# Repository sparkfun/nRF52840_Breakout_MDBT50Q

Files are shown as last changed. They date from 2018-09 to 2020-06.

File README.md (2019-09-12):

SparkFun Pro nRF52840 Mini - Bluetooth Development Board
========================================

SparkFun Pro nRF52840 Mini - Bluetooth Development Board

[*SparkFun Pro nRF52840 Mini - Bluetooth Development Board (DEV-15025)*](https://www.sparkfun.com/products/15025)

<Basic description of the part.>

Repository Contents
-------------------

* **/Documentation** - Data sheets, additional product information
* **/Firmware** -- nRF5 SDK and Arduino firmware components
  * **/Arduino** -- Board definitions and variants for installing in the [nRF52 Arduino Core](https://github.com/adafruit/Adafruit_nRF52_Arduino)
  * **/nRF5_SDK** -- Board definitions for use in the nRF5 SDK.
* **/Hardware** - Eagle design files (.brd, .sch)
* **/Production** - Production panel files (.brd)

Documentation
--------------
* **[Hookup Guide](https://learn.sparkfun.com/tutorials/sparkfun-pro-nrf52840-mini-hookup-guide)** - Basic hookup guide for the Pro nrf52840.

Product Versions
----------------
* [DEV-15025](https://www.sparkfun.com/products/15025)- The SparkFun Pro nRF52840 Mini is a breakout and development board for Nordic Semiconductor’s nRF52840 – a powerful combination of ARM Cortex-M4 CPU and 2.4 GHz Bluetooth radio. With the nRF52840 at the heart of your project, you’ll be presented with a seemingly endless list of project-possibilities.

License Information
-------------------

This product is _**open source**_! 

Please review the LICENSE.md file for license information.

If you have any questions or concerns on licensing, please visit the [SparkFun Forum](https://forum.sparkfun.com/index.php) and post a topic.

Distributed as-is; no warranty is given.

- Your friends at SparkFun.

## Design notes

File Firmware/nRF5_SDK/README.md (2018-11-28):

SparkFun nRF52840 Board Defs for the nRF5 SDK
=============================================

This directory includes any additional board definitions or examples for using the SparkFun nRF52840 boards with Nordic's nRF5 SDK.

The file structure should match that of the SDK.

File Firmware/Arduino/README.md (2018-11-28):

SparkFun Board Variant Definitions for Adafruit nRF52 Arduino Core
==================================================================

### Installation Instructions

To add SparkFun nRF52840 board support to the nRF52 Arduino core, one file (boards.txt) needs to be modified, and one new folder (variants/sparkfun\_nrf52840\_mini) needs to be copied in.

First, navigate to your Adafruit nRF52 core installation. If you installed via the board manager it'll probably be in one of these folders:

* Windows: %LOCALAPPDATA%\Arduino15\packages\adafruit\hardware\nrf52\<version>
* OS X: ~/Library/Arduino15/packages/adafruit/hardware/nrf52/<version>
* Linux: ~/.arduino15/packages/adafruit/hardware/nrf52/<version>

If you installed the core manually into your Arduino sketchbook, it'll be in a "hardware/adafruit/nrf52" in there.

Then **open boards.txt**. Scroll to the bottom and **paste the contents of sparkfun\_boards.txt** into the bottom of that file.

Then copy the contents of the "variants" folder in this directory into the "variants" folder of the original directory. Nothing should be overwritten, but a new "sparkfun\_nrf52840\_mini" directory should be added in.

### Directory Contents

* sparkfun\_boards.txt -- Additional board definitions for SparkFun nRF52840 boards 
* variants/sparkfun\_nrf52840\_mini -- SparkFun Pro nRF52840 Mini board (pin, LED, serial port) definitions.

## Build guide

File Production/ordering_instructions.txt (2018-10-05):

panel size, 174x107mm
PCB thickness, 1.6mm
number of layers, 2
soldermask color, Red
silkscreen color, White
oz copper, 1oz
finish, HASL lead free
stencils, none
pcs per panel, 12

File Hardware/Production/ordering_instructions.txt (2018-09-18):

panel size, 120x107mm
PCB thickness, 1.6mm
number of layers, 2
soldermask color, Black
silkscreen color, White
oz copper, 1oz
finish, HASL lead free
stencils, top
pcs per panel, 8

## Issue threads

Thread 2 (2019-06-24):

Sparkfun Bootloader Firmware

jchidley, 2019-06-24:
I recently corrupted the bootloader on my nRF52840.  I have 2 problems:
1. I need extra hardware to program the bootloader (J-Link for EDU for example or Nordic Semiconductor’s Development Kit).
2. I need a copy of Sparkfun’s  - which is “heavily based on” Adafruit’s.

Where can I find Sparkfun’s version of the firmware?

brhoff720, 2019-07-01:
See [SparkFun Forums](https://forum.sparkfun.com/viewtopic.php?f=114&t=50217) for solution.

Closed 2019-07-01.

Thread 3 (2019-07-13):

Adafruit nRF52 v0.11.1

jakelstr, 2019-07-13:
There seems to be an issue with this when using v0.11.1 of the Adafruit library. On v0.11.1, compiling gives an error that "Serial was not declared in this scope". Reverting to v0.10.1 cleared this error.

masonevans, 2019-07-16:
I experienced the same issue with the same resolution

santaimpersonator, 2019-07-17:
Adafruit switched to using TinyUSB in the core. We made changes in the `variant.cpp` and `boards.txt` files to update the board definition to use TinyUSB.

Using the new files will allow you to compile without this error and to use the example in our hookup guide.

Closed 2019-07-17.

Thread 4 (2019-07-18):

Compile error - fatal error: usb.h: No such file or directory

masonevans, 2019-07-18:
After the latest update seems like there is still an issue in variant.cpp.   I updated to Adafruit nRF52 v0.11.1, updated my boards.txt from the latest version in this repo, and copied the sparkfun_nrf52840_mini directory into my variants folder.

I now get the following error when I try to compile anything with the SparkFun board selected.  The other boards that come with the Adafruit nRF52 board definitions in work fine.

```
/Users/user/Library/Arduino15/packages/adafruit/hardware/nrf52/0.11.1/variants/sparkfun_nrf52840_mini/variant.cpp:26:10: fatal error: usb.h: No such file or directory
 #include "usb.h"
          ^~~~~~~
compilation terminated.
exit status 1
Error compiling for board SparkFun Pro nRF52840 Mini.
```

Commenting out the include from variant.cpp seems to fix the issue.  I do notice that Adafruit removed that include from all their variants when they removed the usb_init() call.

What's odd is that this seemed to work yesterday when I switched to v0.11.1 but today I switched back to v0.10.1 for some testing and when I went back to v0.11.1 I hit this.  Possibly something was cached somewhere?

santaimpersonator, 2019-07-20:
I missed it in the changes I made... to update the board def. Fixed now

Closed 2019-07-20.

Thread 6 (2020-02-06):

SPI issue without V_BUS supplied

deldipso, 2020-02-06:
I notified, the SPI doesn't seems to work if the USB is not plugged (or more directly V_BUS not supplied, it works if V_BUS only is supplied).
So it is not working with a battery or an external power supply on VIN or VBAT if I make a simple project with just SPI.
By not working I means the CLK and MOSI does toggle anymore in that situation. Just the CSB but it is controlled as a simple digital output pin.
This is not an power supply issue. I even unplugged my SPI sensor, I see CLK and MOSI with USB but no anymore with external supply.

SPI CFG:
SPI.begin();
SPI.setClockDivider(SPI_CLOCK_DIV64);
SPI.setDataMode(SPI_MODE2);
SPI.setBitOrder(LSBFIRST);

For an unknow reason, once I started to used the analogWrite() function, the SPI starts to work in any case, which is the workaround I currently use. It seems there is like a GPIO pin initialization issue when V_BUS is not supplied and the SPI only is used without analogWrite()...

Antdigapony, 2021-06-03:
@deldipso I have checked this issue without the USB plugged in and I have found that the problem was with the GND pin. If there is only VIN connected to the 3V3 power supply - there is a problem, that you have mentioned. But if you connect the GND pin from the power supply too - all is OK(by the way it's a correct way of powering).

Maybe, in your case there is something else or whatever, but in my case SPI worked correctly without USB plugged in.

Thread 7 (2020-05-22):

Serial1 Definition Missing

Phando, 2020-05-22:
Hello,
I am just getting started with the nrf52840. The variant does not define Serial1 as specified in the Arduino setup doc

`
Hardware Serial (Serial1) to pins 17 (TX) and 15 (RX) to match the Arduino Pro Mini pinout
`

Should I just double declare Serial1?

```
#define PIN_SERIAL_RX       (15)
#define PIN_SERIAL_TX       (17)
#define PIN_SERIAL1_RX      (15)
#define PIN_SERIAL1_TX      (17)
```

bboyho, 2020-05-29:
Hi,

Interesting... It looks like the nRF52 Arduino core files were updated with some additional features. This update broke a few things related to the UART sometime between [**0.17.0**](https://github.com/adafruit/Adafruit_nRF52_Arduino/blob/0.17.0/cores/nRF5/Uart.cpp#L243) and [**0.16.0**](https://github.com/adafruit/Adafruit_nRF52_Arduino/blob/0.16.0/cores/nRF5/Uart.cpp#L207). This is probably what you are seeeing with the v0.20.0 release:

    C:\Users\user_bob\AppData\Local\Arduino15\packages\adafruit\hardware\nrf52\0.20.1\cores\nRF5\Uart.cpp:247:48: error: 'PIN_SERIAL1_RX' was not declared in this scope

       Uart Serial1( NRF_UARTE0, UARTE0_UART0_IRQn, PIN_SERIAL1_RX, PIN_SERIAL1_TX );

                                                    ^~~~~~~~~~~~~~

    C:\Users\user_bob\AppData\Local\Arduino15\packages\adafruit\hardware\nrf52\0.20.1\cores\nRF5\Uart.cpp:247:48: note: suggested alternative: 'PIN_SERIAL_RX'

       Uart Serial1( NRF_UARTE0, UARTE0_UART0_IRQn, PIN_SERIAL1_RX, PIN_SERIAL1_TX );

                                                    ^~~~~~~~~~~~~~

                                                    PIN_SERIAL_RX

    C:\Users\user_bob\AppData\Local\Arduino15\packages\adafruit\hardware\nrf52\0.20.1\cores\nRF5\Uart.cpp:247:64: error: 'PIN_SERIAL1_TX' was not declared in this scope

       Uart Serial1( NRF_UARTE0, UARTE0_UART0_IRQn, PIN_SERIAL1_RX, PIN_SERIAL1_TX );

                                                                    ^~~~~~~~~~~~~~

    C:\Users\user_bob\AppData\Local\Arduino15\packages\adafruit\hardware\nrf52\0.20.1\cores\nRF5\Uart.cpp:247:64: note: suggested alternative: 'PIN_SERIAL_TX'

       Uart Serial1( NRF_UARTE0, UARTE0_UART0_IRQn, PIN_SERIAL1_RX, PIN_SERIAL1_TX );

                                                                    ^~~~~~~~~~~~~~

                                                                    PIN_SERIAL_TX

    exit status 1
    Error compiling for board SparkFun Pro nRF52840 Mini.

For backward compatibility, it would not hurt to double declare the hardware serial pins. Testing this out with **0.16.0** and **0.20.1** (which is the latest as of today), it did not seem to cause any issues. I was able to still send serial data via Arduino monitor using `Serial.print()`. Using a serial-to-USB converter, I was still able to send/receive serial data via hardware serial pins using  `Serial1.print()`. I'll adjust the **variants.h** file in this repo in case others run into the same issue.

Here's the gist of it if you (or anyone else that comes across this issue)  want to test it out => https://gist.github.com/bboyho/554cdcdac422a8cf07f4f2d870120d38 .

bboyho, 2020-05-29:
And it's been added to this GitHub repo. =)

Closed 2020-05-29.

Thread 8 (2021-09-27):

Issue with LED pin definitions

DeadlyJesus, 2021-09-27:
Hi,
This might be a misunderstanding on my part but, on the board definition for the nRF SDK (sparkfun_nrf52840_mini.h), two leds are declared, yet only one is actually connected on the board.

```C#
define LED_1          NRF_GPIO_PIN_MAP(0,7)
```
This is the definition for the blue user led connected to P0.07 (23)

```C
#define LED_2          NRF_GPIO_PIN_MAP(0,14)
```
This definition is for a led that should be connected to P0.14 (36) yet the schematic show that this pin isn't connected to anything

Shouldn't there be only one LED or am I missing something ? Like this:
```C
#define LEDS_NUMBER    1

#define LED_1          NRF_GPIO_PIN_MAP(0,7)
#define LED_START      LED_1
#define LED_STOP       LED_1

#define LEDS_ACTIVE_STATE 1

#define LEDS_LIST { LED_1 }

#define LEDS_INV_MASK  LEDS_MASK

#define BSP_LED_0      7
```

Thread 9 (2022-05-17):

Bootloader Firmware Source?

cHemingway, 2022-05-17:
The firmware link in the [product page](https://www.sparkfun.com/products/15025) just links to the [adafruit repository](https://github.com/adafruit/Adafruit_nRF52_Bootloader), which does not contain a board definition for the nRF52840 board, and so will not work properly without a board definition being created (wrong name shows up in device manager, wrong pins for LEDs/Buttons etc).

Can a board definition be provided? And (ideally) merged into the Adafruit repo?

cHemingway, 2022-05-17:
I have created a new board ` boards\sparkfun_pro_nrf52840_mini ` based on  `boards\sparkfun_nrf52840_micromod`, and it seems to work.
https://gist.github.com/cHemingway/26a6dba63699b8397ca0682419dc22db

However, I haven't changed the VID/PID from the micromod version, I think each board should have a unique VID/PID

brhoff720, 2022-05-17:
This board should have the following two PID 0x5284 and 0x5285.  SparkFun's VID is 0x1B4F.

cHemingway, 2022-05-20:
Thanks @brhoff720! Do you work for either Adafruit or Sparkfun? If so, are you interested in getting support for this board merged into the Adafruit repo?

A concern I have with submitting a pull request to the Adafruit repo myself, is that that doesn't gaurantee the bootloader programmed on a board when you buy it is actually running that particular code. It would be useful to know what the sparkfun board is actually running

makin-stuff, 2022-05-24:
Hello @cHemingway .
Have you seen this [article by SparkFun](https://learn.sparkfun.com/tutorials/nrf52840-development-with-arduino-and-circuitpython)? It goes into all the details of getting the [Pro nRF52840 Mini](https://www.sparkfun.com/products/15025) set up in the Arduino IDE using the Adafruit core.
Newer products like the [MicroMod nRF52840 Processor Board
](https://www.sparkfun.com/products/16984) use the [Arduino MBed Core](https://learn.sparkfun.com/tutorials/micromod-nrf52840-processor-hookup-guide/arduino-software-setup) with custom boards.txt file and variants for the SF product.

cHemingway, 2022-05-24:
Hi @makin-stuff

I don't think this is completed, as I don't have the source code for the bootloader, which was my question. I am interested in it as it sets things like the Nordic Softdevice used.
Instead, you've pointed me at some other things, which I don't think are related?

- An article on how to use CircuitPython and Arduino, which isn't the bootloader source. Instead, the article just says the board _uses_ a bootloader, but doesn't tell you anything else about it.

- Information on other boards, which I'm not using

- Boards.txt, which is Arduino (not CircuitPython), and isn't what I'm looking for.

If Sparkfun don't want to share the source code, that would be an answer to my question, though not my preferred answer of course!

makin-stuff, 2022-05-25:
Alrighty @cHemingway.

I did some searching and I don't think we have the bootloader source firmware for this product and the original engineer no longer works at SparkFun. It is likely that one of the feather board definitions (feather_nrf52840_express or feather_nrf52840_sense) from this [repo](https://github.com/adafruit/Adafruit_nRF52_Bootloader) was used to generate the binaries we use to upload to the SF Pro nRF52840 Mini and he never created a pull request to add those defs to the Adafruit repo.

Additionally, one of our production steps is uploading this [softdevice hex file](https://github.com/NordicSemiconductor/nRF5-SDK-for-Mesh/blob/master/bin/softdevice/s140_nrf52_6.1.1_softdevice.hex) from this [repo.](https://github.com/NordicSemiconductor/nRF5-SDK-for-Mesh)

I also double-checked the PID/VID's given by @brhoff720 and those are correct!

Sorry I couldn't be of more help.

cHemingway, 2022-05-26:
@makin-stuff

OK thanks, I appreciate you chasing this one down!
Maybe the product page could be updated with a link to the binaries instead?

Closed 2022-05-24.

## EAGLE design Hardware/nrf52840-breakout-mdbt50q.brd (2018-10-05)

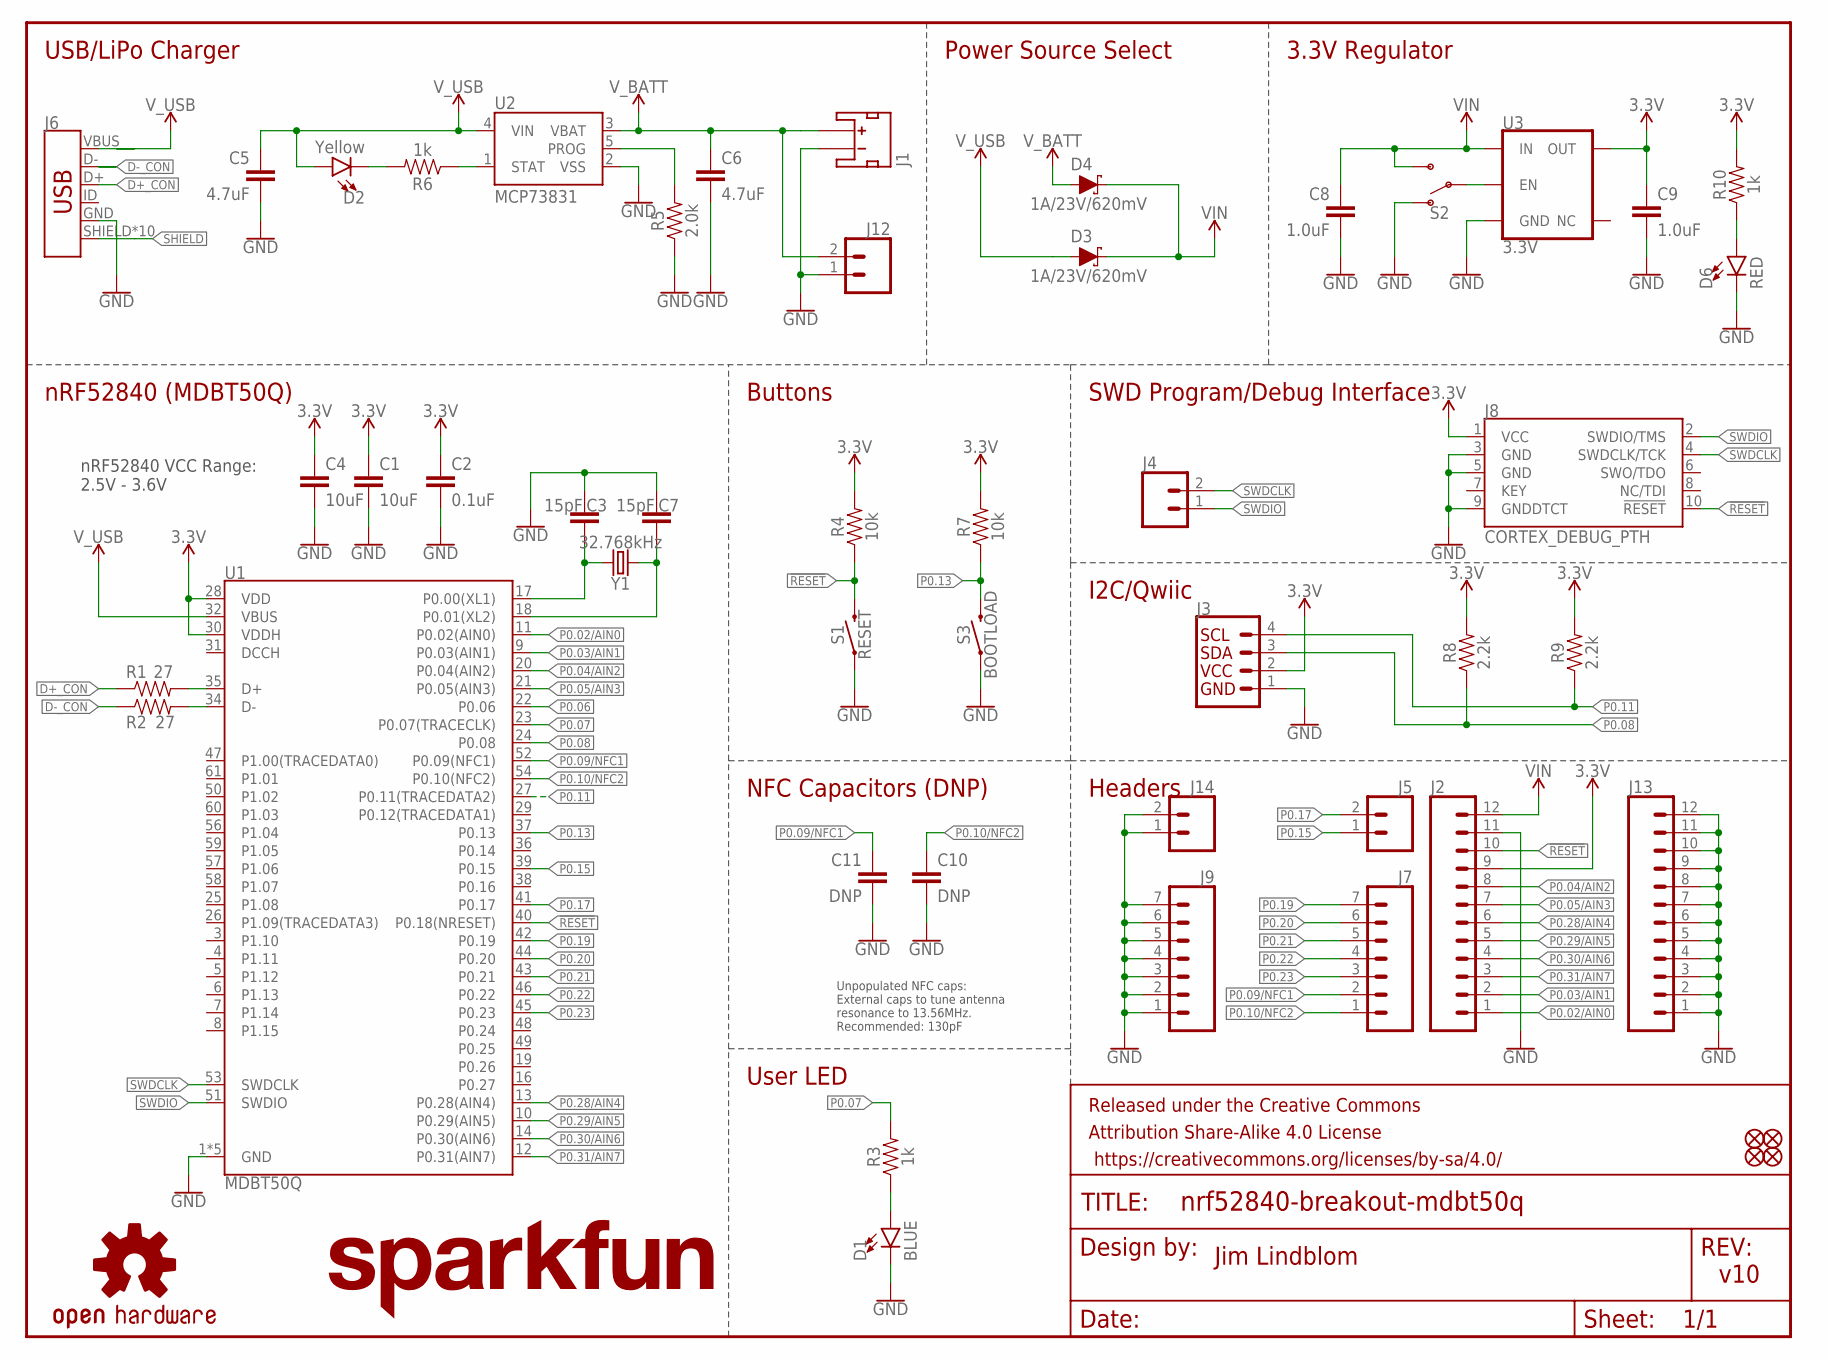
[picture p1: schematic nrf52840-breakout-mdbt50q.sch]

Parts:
C1, C4: 10uF; 0603
C2: 0.1uF; 0603
C3, C7: 15pF; 0603
C5, C6: 4.7uF; 0603
C8, C9: 1.0uF; 0603
C10, C11: DNP; 0603
D1: BLUE; LED-0603
D2: Yellow; LED-0603
D3, D4: 1A/23V/620mV; SOD-323
D6: RED; LED-0603
FD1, FD2, FD3, FD4: FIDUCIALUFIDUCIAL; FIDUCIAL-MICRO
FRAME1: FRAME-LETTER; CREATIVE_COMMONS
J1: JST_2MM_MALESMD; JST-2-SMD
J2, J13: CONN_12NO_SILK; 1X12_NO_SILK
J3: QWIIC_CONNECTORJS-1MM; 1X04_1MM_RA
J4, J5, J12, J14: CONN_021X02_NO_SILK; 1X02_NO_SILK
J6: USB_MICRO-B_HALF_PTH_MILL; USB-MICROB-PTH-MILL
J7, J9: CONN_07NO_SILK; 1X07_NO_SILK
J8: CORTEX_DEBUG_PTH; 2X5-PTH-1.27MM
LOGO1: SFE_LOGO_NAME.2_INCH; SFE_LOGO_NAME_.2
LOGO2: OSHW-LOGOS; OSHW-LOGO-S
R1, R2: 27; 0603
R3, R6, R10: 1k; 0603
R4, R7: 10k; 0603
R5: 2.0k; 0603
R8, R9: 2.2k; 0603
S1: RESET; TACTILE_SWITCH_SMD_RIGHT_ANGLE
S2: SWITCH-SPDT-SMD-RIGHT-ANGLE; SWITCH_SPST_SMD_A
S3: BOOTLOAD; TACTILE_SWITCH_SMD_RIGHT_ANGLE
U1: MDBT50Q
U2: MCP73831; SOT23-5
U3: 3.3V; SOT23-5
Y1: 32.768kHz; CRYSTAL-SMD-3.2X1.5MM

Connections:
3.3V: C1.1, C2.1, C4.1, C9.1, J2.9, J3.2, J8.1 (VCC), R4.2, R7.2, R8.2, R9.2, R10.2, U1.28 (VDD), U1.30 (VDDH), U3.5 (OUT)
!RESET: J2.10, J8.10 (!RESET), R4.1, S1.2, U1.40 (P0.18(NRESET))
D+: R1.2, U1.35 (D+)
D+_CON: J6.D+, R1.1
D-: R2.2, U1.34 (D-)
D-_CON: J6.D-, R2.1
GND: C1.2, C2.2, C3.1, C4.2, C5.2, C6.2, C7.1, C8.2, C9.2, C10.2, C11.2, D1.C, D6.C, J1.1 (-), J2.11, J3.1, J6.GND, J8.3 (GND), J8.5 (GND), J8.9 (GNDDTCT), J9.1, J9.2, J9.3, J9.4, J9.5, J9.6, J9.7, J12.1, J13.1, J13.2, J13.3, J13.4, J13.5, J13.6, J13.7, J13.8, J13.9, J13.10, J13.11, J13.12, J14.1, J14.2, R5.1, S1.1, S2.1 (O), S3.1, U1.1 (GND), U1.2 (GND), U1.15 (GND), U1.33 (GND), U1.55 (GND), U2.2 (VSS), U3.2 (GND)
unnamed: R5.2, U2.5 (PROG)
unnamed: D2.C, R6.2
unnamed: R6.1, U2.1 (STAT)
unnamed: D1.A, R3.1
unnamed: D6.A, R10.1
P0.02/AIN0: J2.1, U1.11 (P0.02(AIN0))
P0.03/AIN1: J2.2, U1.9 (P0.03(AIN1))
P0.04/AIN2: J2.8, U1.20 (P0.04(AIN2))
P0.05/AIN3: J2.7, U1.21 (P0.05(AIN3))
P0.06: U1.22 (P0.06)
P0.07: R3.2, U1.23 (P0.07(TRACECLK))
P0.08: J3.3, R8.1, U1.24 (P0.08)
P0.09/NFC1: C11.1, J7.2, U1.52 (P0.09(NFC1))
P0.10/NFC2: C10.1, J7.1, U1.54 (P0.10(NFC2))
P0.11: J3.4, R9.1, U1.27 (P0.11(TRACEDATA2))
P0.13: R7.1, S3.2, U1.37 (P0.13)
P0.15: J5.1, U1.39 (P0.15)
P0.17: J5.2, U1.41 (P0.17)
P0.19: J7.7, U1.42 (P0.19)
P0.20: J7.6, U1.44 (P0.20)
P0.21: J7.5, U1.43 (P0.21)
P0.22: J7.4, U1.46 (P0.22)
P0.23: J7.3, U1.45 (P0.23)
P0.28/AIN4: J2.6, U1.13 (P0.28(AIN4))
P0.29/AIN5: J2.5, U1.10 (P0.29(AIN5))
P0.30/AIN6: J2.4, U1.14 (P0.30(AIN6))
P0.31/AIN7: J2.3, U1.12 (P0.31(AIN7))
SHIELD: J6.SHIELD, J6.SHIELD2 (SHIELD), J6.SHIELD3 (SHIELD), J6.SHIELD4 (SHIELD), J6.SHIELD5 (SHIELD), J6.SHIELD6 (SHIELD), J6.SHIELD7 (SHIELD), J6.SHIELD8 (SHIELD), J6.SHIELD9 (SHIELD), J6.SHIELD10 (SHIELD)
SWDCLK: J4.2, J8.4 (SWDCLK/TCK), U1.53 (SWDCLK)
SWDIO: J4.1, J8.2 (SWDIO/TMS), U1.51 (SWDIO)
VIN: C8.1, D3.C, D4.C, J2.12, S2.3 (S), U3.1 (IN)
VREG_EN: S2.2, U3.3 (EN)
V_BATT: C6.1, D4.A, J1.2 (+), J12.2, U2.3 (VBAT)
V_USB: C5.1, D2.A, D3.A, J6.VBUS, U1.32 (VBUS), U2.4 (VIN)
XL1: C3.2, U1.17 (P0.00(XL1)), Y1.P$2 (2)
XL2: C7.2, U1.18 (P0.01(XL2)), Y1.P$1 (1)

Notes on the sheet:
v10
Jim Lindblom
SWD Program/Debug Interface
I2C/Qwiic
Headers
NFC Capacitors (DNP)
Buttons
User LED
nRF52840 (MDBT50Q)
USB/LiPo Charger
Power Source Select
3.3V Regulator
Unpopulated NFC caps: External caps to tune antenna resonance to 13.56MHz. Recommended: 130pF
nRF52840 VCC Range: 2.5V - 3.6V

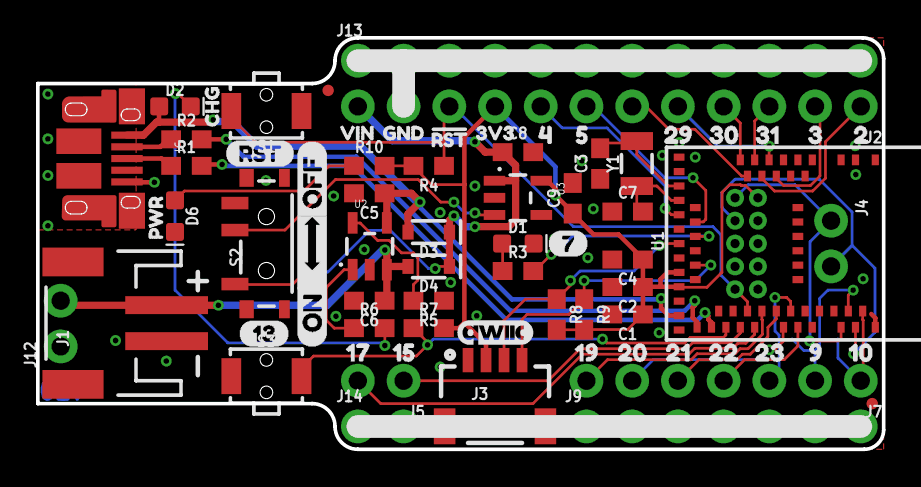
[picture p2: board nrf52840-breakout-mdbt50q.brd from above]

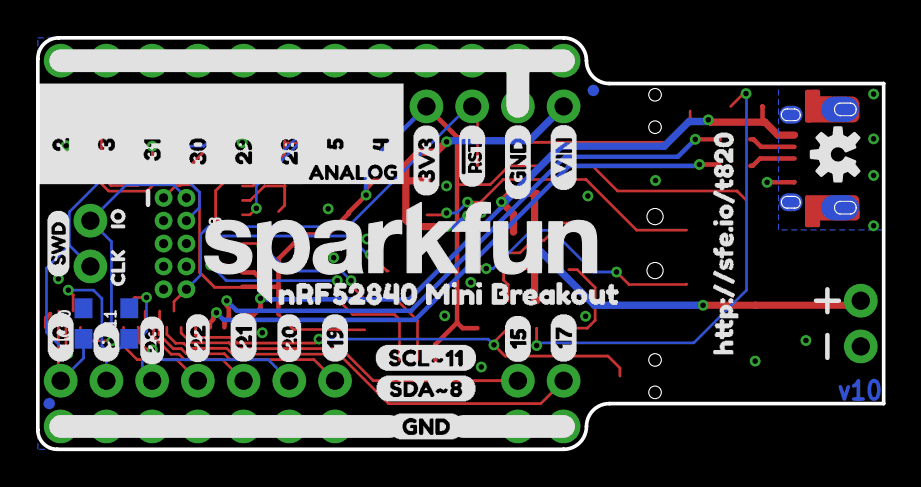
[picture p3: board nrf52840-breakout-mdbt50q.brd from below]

Board: 2 copper layers, 47.0 x 22.9 mm, 110 parts (37 on the bottom side), 42 nets.

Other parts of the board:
U$1: 3V316
U$2: 130
U$3: RST19
U$4: ON1
U$5: CHG26
U$6: PWR27
U$7: GND17
U$8: QWIIC#LOGO#JPG
U$9: 20
U$10: 31
U$11: 292
U$12: 313
U$13: 3V30
U$14: 285
U$15: 521
U$16: 421
U$17: HTTP###SFE#IO#T8200
U$18: #RST6
U$19: GND7
U$20: VIN8
U$21: 1022
U$22: 916
U$23: 2111
U$24: 1912
U$25: 1713
U$26: 1522
U$27: VIN19
U$28: 70
U$29: NRF52840_MINI_BREAKOUT0
U$30: GND6
U$31: 27
U$32: 36
U$33: SWD0
U$34: 315
U$35: 300
U$36: 301
U$37: 293
U$38: 108
U$39: 51
U$40: 40
U$41: 97
U$42: 236
U$43: 200
U$44: 225
U$45: 221
U$46: 214
U$47: 203
U$48: 192
U$49: 151
U$50: 170
U$51: RST1
U$52: ANALOG2
U$53: 232
U$54: SCL#114
U$55: SDA#83
U$56: IO2
U$57: CLK1
U$58: OFF2

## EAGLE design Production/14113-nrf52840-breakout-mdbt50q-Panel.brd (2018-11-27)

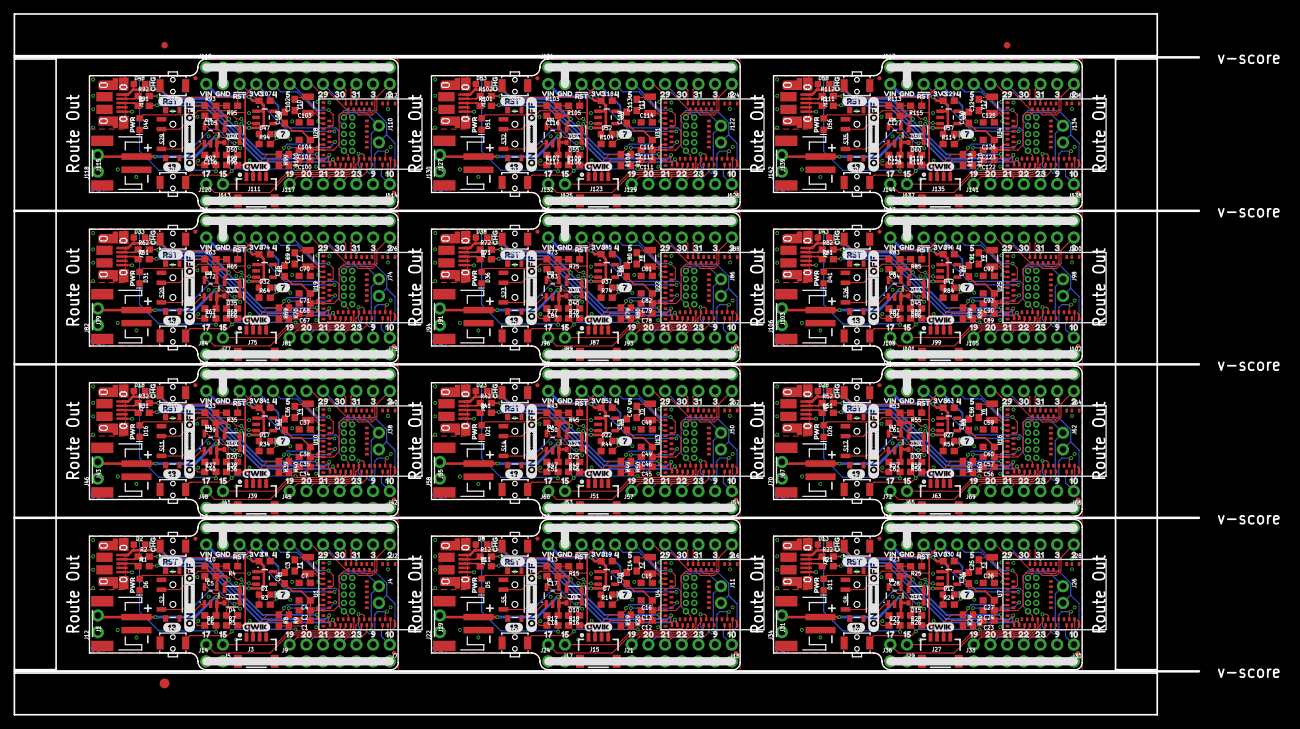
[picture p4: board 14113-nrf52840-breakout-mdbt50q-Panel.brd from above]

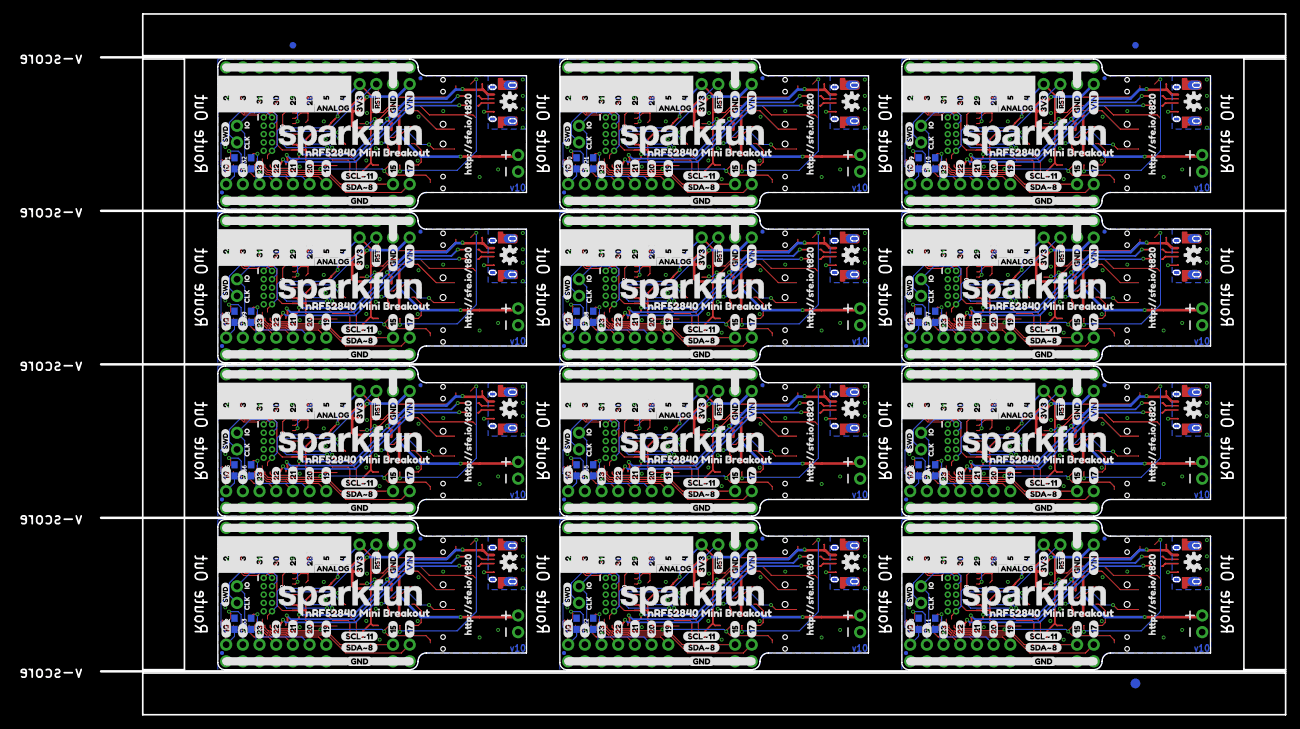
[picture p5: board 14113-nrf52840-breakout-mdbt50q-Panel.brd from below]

Board: 2 copper layers, 180.3 x 106.7 mm, 1314 parts (447 on the bottom side), 504 nets.

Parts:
C1, C4, C12, C16, C23, C27, C34, C38, C45, C49, C56, C60, C67, C71, C78, C82, C89, C93, C100, C104, C111, C115, C122, C126: 10uF; 0603
C2, C13, C24, C35, C46, C57, C68, C79, C90, C101, C112, C123: 0.1uF; 0603
C3, C7, C14, C15, C25, C26, C36, C37, C47, C48, C58, C59, C69, C70, C80, C81, C91, C92, C102, C103, C113, C114, C124, C125: 15pF; 0603
C5, C6, C17, C18, C28, C29, C39, C40, C50, C51, C61, C62, C72, C73, C83, C84, C94, C95, C105, C106, C116, C117, C127, C128: 4.7uF; 0603
C8, C9, C19, C20, C30, C31, C41, C42, C52, C53, C63, C64, C74, C75, C85, C86, C96, C97, C107, C108, C118, C119, C129, C130: 1.0uF; 0603
C10, C11, C21, C22, C32, C33, C43, C44, C54, C55, C65, C66, C76, C77, C87, C88, C98, C99, C109, C110, C120, C121, C131, C132: DNP; 0603
D1, D7, D12, D17, D22, D27, D32, D37, D42, D47, D52, D57: BLUE; LED-0603
D2, D8, D13, D18, D23, D28, D33, D38, D43, D48, D53, D58: Yellow; LED-0603
D3, D4, D9, D10, D14, D15, D19, D20, D24, D25, D29, D30, D34, D35, D39, D40, D44, D45, D49, D50, D54, D55, D59, D60: 1A/23V/620mV; SOD-323
D5, D6, D11, D16, D21, D26, D31, D36, D41, D46, D51, D56: RED; LED-0603
E$1, E$2, E$3, E$4: FIDUCIAL-1X2
E$5, E$6: FIDUCIAL-1.5X3
FD1, FD2, FD3, FD4, FD5, FD6, FD7, FD8, FD9, FD10, FD11, FD12, FD13, FD14, FD15, FD16, FD17, FD18, FD19, FD20, FD21, FD22, FD23, FD24, FD25, FD26, FD27, FD28, FD29, FD30, FD31, FD32, FD33, FD34, FD35, FD36, FD37, FD38, FD39, FD40, FD41, FD42, FD43, FD44, FD45, FD46, FD47, FD48: FIDUCIALUFIDUCIAL; FIDUCIAL-MICRO
J1, J19, J31, J43, J55, J67, J79, J91, J103, J115, J127, J139: JST-2-SMD
J2, J13, J16, J23, J28, J35, J40, J47, J52, J59, J64, J71, J76, J83, J88, J95, J100, J107, J112, J119, J124, J131, J136, J143: 1X12_NO_SILK
J3, J15, J27, J39, J51, J63, J75, J87, J99, J111, J123, J135: 1X04_1MM_RA
J4, J5, J11, J12, J14, J17, J22, J24, J26, J29, J34, J36, J38, J41, J46, J48, J50, J53, J58, J60, J62, J65, J70, J72, J74, J77, J82, J84, J86, J89, J94, J96, J98, J101, J106, J108, J110, J113, J118, J120, J122, J125, J130, J132, J134, J137, J142, J144: 1X02_NO_SILK
J6, J10, J25, J37, J49, J61, J73, J85, J97, J109, J121, J133: USB-MICROB-PTH-MILL
J7, J9, J18, J21, J30, J33, J42, J45, J54, J57, J66, J69, J78, J81, J90, J93, J102, J105, J114, J117, J126, J129, J138, J141: 1X07_NO_SILK
J8, J20, J32, J44, J56, J68, J80, J92, J104, J116, J128, J140: CORTEX_DEBUG_PTH; 2X5-PTH-1.27MM
LOGO1, LOGO3, LOGO5, LOGO7, LOGO9, LOGO11, LOGO13, LOGO15, LOGO17, LOGO19, LOGO21, LOGO23: SFE_LOGO_NAME.2_INCH; SFE_LOGO_NAME_.2
LOGO2, LOGO4, LOGO6, LOGO8, LOGO10, LOGO12, LOGO14, LOGO16, LOGO18, LOGO20, LOGO22, LOGO24: OSHW-LOGOS; OSHW-LOGO-S
R1, R2, R11, R12, R21, R22, R31, R32, R41, R42, R51, R52, R61, R62, R71, R72, R81, R82, R91, R92, R101, R102, R111, R112: 27; 0603
R3, R6, R10, R13, R14, R17, R23, R24, R27, R33, R34, R37, R43, R44, R47, R53, R54, R57, R63, R64, R67, R73, R74, R77, R83, R84, R87, R93, R94, R97, R103, R104, R107, R113, R114, R117: 1k; 0603
R4, R7, R15, R18, R25, R28, R35, R38, R45, R48, R55, R58, R65, R68, R75, R78, R85, R88, R95, R98, R105, R108, R115, R118: 10k; 0603
R5, R16, R26, R36, R46, R56, R66, R76, R86, R96, R106, R116: 2.0k; 0603
R8, R9, R19, R20, R29, R30, R39, R40, R49, R50, R59, R60, R69, R70, R79, R80, R89, R90, R99, R100, R109, R110, R119, R120: 2.2k; 0603
S1, S4, S7, S10, S13, S16, S19, S22, S25, S28, S31, S34: RESET; TACTILE_SWITCH_SMD_RIGHT_ANGLE
S2, S5, S8, S11, S14, S17, S20, S23, S26, S29, S32, S35: SWITCH_SPST_SMD_A
S3, S6, S9, S12, S15, S18, S21, S24, S27, S30, S33, S36: BOOTLOAD; TACTILE_SWITCH_SMD_RIGHT_ANGLE
U1, U4, U7, U10, U13, U16, U19, U22, U25, U28, U31, U34: MDBT50Q
U2, U5, U8, U11, U14, U17, U20, U23, U26, U29, U32, U35: MCP73831; SOT23-5
U3, U6, U9, U12, U15, U18, U21, U24, U27, U30, U33, U36: 3.3V; SOT23-5
U$1, U$92, U$150, U$208, U$266, U$324, U$382, U$440, U$498, U$556, U$614, U$672: 3V316
U$2, U$109, U$167, U$225, U$283, U$341, U$399, U$457, U$515, U$573, U$631, U$689: 130
U$3, U$91, U$149, U$207, U$265, U$323, U$381, U$439, U$497, U$555, U$613, U$671: RST19
U$4, U$113, U$171, U$229, U$287, U$345, U$403, U$461, U$519, U$577, U$635, U$693: ON1
U$5, U$59, U$117, U$175, U$233, U$291, U$349, U$407, U$465, U$523, U$581, U$639: CHG26
U$6, U$60, U$118, U$176, U$234, U$292, U$350, U$408, U$466, U$524, U$582, U$640: PWR27
U$7, U$89, U$147, U$205, U$263, U$321, U$379, U$437, U$495, U$553, U$611, U$669: GND17
U$8, U$87, U$145, U$203, U$261, U$319, U$377, U$435, U$493, U$551, U$609, U$667: QWIIC#LOGO#JPG
U$9, U$62, U$120, U$178, U$236, U$294, U$352, U$410, U$468, U$526, U$584, U$642: 20
U$10, U$63, U$121, U$179, U$237, U$295, U$353, U$411, U$469, U$527, U$585, U$643: 31
U$11, U$64, U$122, U$180, U$238, U$296, U$354, U$412, U$470, U$528, U$586, U$644: 292
U$12, U$65, U$123, U$181, U$239, U$297, U$355, U$413, U$471, U$529, U$587, U$645: 313
U$13, U$111, U$169, U$227, U$285, U$343, U$401, U$459, U$517, U$575, U$633, U$691: 3V30
U$14, U$66, U$124, U$182, U$240, U$298, U$356, U$414, U$472, U$530, U$588, U$646: 285
U$15, U$67, U$125, U$183, U$241, U$299, U$357, U$415, U$473, U$531, U$589, U$647: 521
U$16, U$68, U$126, U$184, U$242, U$300, U$358, U$416, U$474, U$532, U$590, U$648: 421
U$17, U$112, U$170, U$228, U$286, U$344, U$402, U$460, U$518, U$576, U$634, U$692: HTTP###SFE#IO#T8200
U$18, U$69, U$127, U$185, U$243, U$301, U$359, U$417, U$475, U$533, U$591, U$649: #RST6
U$19, U$70, U$128, U$186, U$244, U$302, U$360, U$418, U$476, U$534, U$592, U$650: GND7
U$20, U$71, U$129, U$187, U$245, U$303, U$361, U$419, U$477, U$535, U$593, U$651: VIN8
U$21, U$72, U$130, U$188, U$246, U$304, U$362, U$420, U$478, U$536, U$594, U$652: 1022
U$22, U$73, U$131, U$189, U$247, U$305, U$363, U$421, U$479, U$537, U$595, U$653: 916
U$23, U$74, U$132, U$190, U$248, U$306, U$364, U$422, U$480, U$538, U$596, U$654: 2111
U$24, U$75, U$133, U$191, U$249, U$307, U$365, U$423, U$481, U$539, U$597, U$655: 1912
U$25, U$76, U$134, U$192, U$250, U$308, U$366, U$424, U$482, U$540, U$598, U$656: 1713
U$26, U$77, U$135, U$193, U$251, U$309, U$367, U$425, U$483, U$541, U$599, U$657: 1522
U$27, U$90, U$148, U$206, U$264, U$322, U$380, U$438, U$496, U$554, U$612, U$670: VIN19
U$28, U$88, U$146, U$204, U$262, U$320, U$378, U$436, U$494, U$552, U$610, U$668: 70
U$29, U$86, U$144, U$202, U$260, U$318, U$376, U$434, U$492, U$550, U$608, U$666: NRF52840_MINI_BREAKOUT0
U$30, U$61, U$119, U$177, U$235, U$293, U$351, U$409, U$467, U$525, U$583, U$641: GND6
U$31, U$93, U$151, U$209, U$267, U$325, U$383, U$441, U$499, U$557, U$615, U$673: 27
U$32, U$94, U$152, U$210, U$268, U$326, U$384, U$442, U$500, U$558, U$616, U$674: 36
U$33, U$83, U$141, U$199, U$257, U$315, U$373, U$431, U$489, U$547, U$605, U$663: SWD0
U$34, U$95, U$153, U$211, U$269, U$327, U$385, U$443, U$501, U$559, U$617, U$675: 315
U$35, U$110, U$168, U$226, U$284, U$342, U$400, U$458, U$516, U$574, U$632, U$690: 300
U$36, U$116, U$174, U$232, U$290, U$348, U$406, U$464, U$522, U$580, U$638, U$696: 301
U$37, U$96, U$154, U$212, U$270, U$328, U$386, U$444, U$502, U$560, U$618, U$676: 293
U$38, U$99, U$157, U$215, U$273, U$331, U$389, U$447, U$505, U$563, U$621, U$679: 108
U$39, U$97, U$155, U$213, U$271, U$329, U$387, U$445, U$503, U$561, U$619, U$677: 51
U$40, U$98, U$156, U$214, U$272, U$330, U$388, U$446, U$504, U$562, U$620, U$678: 40
U$41, U$100, U$158, U$216, U$274, U$332, U$390, U$448, U$506, U$564, U$622, U$680: 97
U$42, U$101, U$159, U$217, U$275, U$333, U$391, U$449, U$507, U$565, U$623, U$681: 236
U$43, U$78, U$136, U$194, U$252, U$310, U$368, U$426, U$484, U$542, U$600, U$658: 200
U$44, U$102, U$160, U$218, U$276, U$334, U$392, U$450, U$508, U$566, U$624, U$682: 225
U$45, U$79, U$137, U$195, U$253, U$311, U$369, U$427, U$485, U$543, U$601, U$659: 221
U$46, U$103, U$161, U$219, U$277, U$335, U$393, U$451, U$509, U$567, U$625, U$683: 214
U$47, U$104, U$162, U$220, U$278, U$336, U$394, U$452, U$510, U$568, U$626, U$684: 203
U$48, U$105, U$163, U$221, U$279, U$337, U$395, U$453, U$511, U$569, U$627, U$685: 192
U$49, U$106, U$164, U$222, U$280, U$338, U$396, U$454, U$512, U$570, U$628, U$686: 151
U$50, U$107, U$165, U$223, U$281, U$339, U$397, U$455, U$513, U$571, U$629, U$687: 170
U$51, U$108, U$166, U$224, U$282, U$340, U$398, U$456, U$514, U$572, U$630, U$688: RST1
U$52, U$115, U$173, U$231, U$289, U$347, U$405, U$463, U$521, U$579, U$637, U$695: ANALOG2
U$53, U$80, U$138, U$196, U$254, U$312, U$370, U$428, U$486, U$544, U$602, U$660: 232
U$54, U$81, U$139, U$197, U$255, U$313, U$371, U$429, U$487, U$545, U$603, U$661: SCL#114
U$55, U$82, U$140, U$198, U$256, U$314, U$372, U$430, U$488, U$546, U$604, U$662: SDA#83
U$56, U$84, U$142, U$200, U$258, U$316, U$374, U$432, U$490, U$548, U$606, U$664: IO2
U$57, U$85, U$143, U$201, U$259, U$317, U$375, U$433, U$491, U$549, U$607, U$665: CLK1
U$58, U$114, U$172, U$230, U$288, U$346, U$404, U$462, U$520, U$578, U$636, U$694: OFF2
Y1, Y2, Y3, Y4, Y5, Y6, Y7, Y8, Y9, Y10, Y11, Y12: 32.768kHz; CRYSTAL-SMD-3.2X1.5MM

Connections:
3.3V: C1.1, C2.1, C4.1, C9.1, J2.9, J3.2, J8.1, R4.2, R7.2, R8.2, R9.2, R10.2, U1.28, U1.30, U3.5
3.3V1: C12.1, C13.1, C16.1, C20.1, J15.2, J16.9, J20.1, R13.2, R15.2, R18.2, R19.2, R20.2, U4.28, U4.30, U6.5
3.3V2: C23.1, C24.1, C27.1, C31.1, J27.2, J28.9, J32.1, R23.2, R25.2, R28.2, R29.2, R30.2, U7.28, U7.30, U9.5
3.3V3: C34.1, C35.1, C38.1, C42.1, J39.2, J40.9, J44.1, R33.2, R35.2, R38.2, R39.2, R40.2, U10.28, U10.30, U12.5
3.3V4: C45.1, C46.1, C49.1, C53.1, J51.2, J52.9, J56.1, R43.2, R45.2, R48.2, R49.2, R50.2, U13.28, U13.30, U15.5
3.3V5: C56.1, C57.1, C60.1, C64.1, J63.2, J64.9, J68.1, R53.2, R55.2, R58.2, R59.2, R60.2, U16.28, U16.30, U18.5
3.3V6: C67.1, C68.1, C71.1, C75.1, J75.2, J76.9, J80.1, R63.2, R65.2, R68.2, R69.2, R70.2, U19.28, U19.30, U21.5
3.3V7: C78.1, C79.1, C82.1, C86.1, J87.2, J88.9, J92.1, R73.2, R75.2, R78.2, R79.2, R80.2, U22.28, U22.30, U24.5
3.3V8: C89.1, C90.1, C93.1, C97.1, J99.2, J100.9, J104.1, R83.2, R85.2, R88.2, R89.2, R90.2, U25.28, U25.30, U27.5
3.3V9: C100.1, C101.1, C104.1, C108.1, J111.2, J112.9, J116.1, R93.2, R95.2, R98.2, R99.2, R100.2, U28.28, U28.30, U30.5
3.3V10: C111.1, C112.1, C115.1, C119.1, J123.2, J124.9, J128.1, R103.2, R105.2, R108.2, R109.2, R110.2, U31.28, U31.30, U33.5
3.3V11: C122.1, C123.1, C126.1, C130.1, J135.2, J136.9, J140.1, R113.2, R115.2, R118.2, R119.2, R120.2, U34.28, U34.30, U36.5
!RESET: J2.10, J8.10, R4.1, S1.2, U1.40
!RESET1: J16.10, J20.10, R15.1, S4.2, U4.40
!RESET2: J28.10, J32.10, R25.1, S7.2, U7.40
!RESET3: J40.10, J44.10, R35.1, S10.2, U10.40
!RESET4: J52.10, J56.10, R45.1, S13.2, U13.40
!RESET5: J64.10, J68.10, R55.1, S16.2, U16.40
!RESET6: J76.10, J80.10, R65.1, S19.2, U19.40
!RESET7: J88.10, J92.10, R75.1, S22.2, U22.40
!RESET8: J100.10, J104.10, R85.1, S25.2, U25.40
!RESET9: J112.10, J116.10, R95.1, S28.2, U28.40
!RESET10: J124.10, J128.10, R105.1, S31.2, U31.40
!RESET11: J136.10, J140.10, R115.1, S34.2, U34.40
D+: R1.2, U1.35
D+1: R11.2, U4.35
D+2: R21.2, U7.35
D+3: R31.2, U10.35
D+4: R41.2, U13.35
D+5: R51.2, U16.35
D+6: R61.2, U19.35
D+7: R71.2, U22.35
D+8: R81.2, U25.35
D+9: R91.2, U28.35
D+10: R101.2, U31.35
D+11: R111.2, U34.35
D+_CON: J6.D+, R1.1
D+_CON1: J10.D+, R11.1
D+_CON2: J25.D+, R21.1
D+_CON3: J37.D+, R31.1
D+_CON4: J49.D+, R41.1
D+_CON5: J61.D+, R51.1
D+_CON6: J73.D+, R61.1
D+_CON7: J85.D+, R71.1
D+_CON8: J97.D+, R81.1
D+_CON9: J109.D+, R91.1
D+_CON10: J121.D+, R101.1
D+_CON11: J133.D+, R111.1
D-: R2.2, U1.34
D-1: R12.2, U4.34
D-2: R22.2, U7.34
D-3: R32.2, U10.34
D-4: R42.2, U13.34
D-5: R52.2, U16.34
D-6: R62.2, U19.34
D-7: R72.2, U22.34
D-8: R82.2, U25.34
D-9: R92.2, U28.34
D-10: R102.2, U31.34
D-11: R112.2, U34.34
D-_CON: J6.D-, R2.1
D-_CON1: J10.D-, R12.1
D-_CON2: J25.D-, R22.1
D-_CON3: J37.D-, R32.1
D-_CON4: J49.D-, R42.1
D-_CON5: J61.D-, R52.1
D-_CON6: J73.D-, R62.1
D-_CON7: J85.D-, R72.1
D-_CON8: J97.D-, R82.1
D-_CON9: J109.D-, R92.1
D-_CON10: J121.D-, R102.1
D-_CON11: J133.D-, R112.1
GND: C1.2, C2.2, C3.1, C4.2, C5.2, C6.2, C7.1, C8.2, C9.2, C10.2, C11.2, D1.C, D6.C, J1.1, J2.11, J3.1, J6.GND, J8.3, J8.5, J8.9, J9.1, J9.2, J9.3, J9.4, J9.5, J9.6, J9.7, J12.1, J13.1, J13.2, J13.3, J13.4, J13.5, J13.6, J13.7, J13.8, J13.9, J13.10, J13.11, J13.12, J14.1, J14.2, R5.1, S1.1, S2.1, S3.1, U1.1, U1.2, U1.15, U1.33, U1.55, U2.2, U3.2
GND1: C12.2, C13.2, C14.1, C15.1, C16.2, C17.2, C18.2, C19.2, C20.2, C21.2, C22.2, D5.C, D7.C, J10.GND, J15.1, J16.11, J19.1, J20.3, J20.5, J20.9, J21.1, J21.2, J21.3, J21.4, J21.5, J21.6, J21.7, J22.1, J23.1, J23.2, J23.3, J23.4, J23.5, J23.6, J23.7, J23.8, J23.9, J23.10, J23.11, J23.12, J24.1, J24.2, R16.1, S4.1, S5.1, S6.1, U4.1, U4.2, U4.15, U4.33, U4.55, U5.2, U6.2
GND2: C23.2, C24.2, C25.1, C26.1, C27.2, C28.2, C29.2, C30.2, C31.2, C32.2, C33.2, D11.C, D12.C, J25.GND, J27.1, J28.11, J31.1, J32.3, J32.5, J32.9, J33.1, J33.2, J33.3, J33.4, J33.5, J33.6, J33.7, J34.1, J35.1, J35.2, J35.3, J35.4, J35.5, J35.6, J35.7, J35.8, J35.9, J35.10, J35.11, J35.12, J36.1, J36.2, R26.1, S7.1, S8.1, S9.1, U7.1, U7.2, U7.15, U7.33, U7.55, U8.2, U9.2
GND3: C34.2, C35.2, C36.1, C37.1, C38.2, C39.2, C40.2, C41.2, C42.2, C43.2, C44.2, D16.C, D17.C, J37.GND, J39.1, J40.11, J43.1, J44.3, J44.5, J44.9, J45.1, J45.2, J45.3, J45.4, J45.5, J45.6, J45.7, J46.1, J47.1, J47.2, J47.3, J47.4, J47.5, J47.6, J47.7, J47.8, J47.9, J47.10, J47.11, J47.12, J48.1, J48.2, R36.1, S10.1, S11.1, S12.1, U10.1, U10.2, U10.15, U10.33, U10.55, U11.2, U12.2
GND4: C45.2, C46.2, C47.1, C48.1, C49.2, C50.2, C51.2, C52.2, C53.2, C54.2, C55.2, D21.C, D22.C, J49.GND, J51.1, J52.11, J55.1, J56.3, J56.5, J56.9, J57.1, J57.2, J57.3, J57.4, J57.5, J57.6, J57.7, J58.1, J59.1, J59.2, J59.3, J59.4, J59.5, J59.6, J59.7, J59.8, J59.9, J59.10, J59.11, J59.12, J60.1, J60.2, R46.1, S13.1, S14.1, S15.1, U13.1, U13.2, U13.15, U13.33, U13.55, U14.2, U15.2
GND5: C56.2, C57.2, C58.1, C59.1, C60.2, C61.2, C62.2, C63.2, C64.2, C65.2, C66.2, D26.C, D27.C, J61.GND, J63.1, J64.11, J67.1, J68.3, J68.5, J68.9, J69.1, J69.2, J69.3, J69.4, J69.5, J69.6, J69.7, J70.1, J71.1, J71.2, J71.3, J71.4, J71.5, J71.6, J71.7, J71.8, J71.9, J71.10, J71.11, J71.12, J72.1, J72.2, R56.1, S16.1, S17.1, S18.1, U16.1, U16.2, U16.15, U16.33, U16.55, U17.2, U18.2
GND6: C67.2, C68.2, C69.1, C70.1, C71.2, C72.2, C73.2, C74.2, C75.2, C76.2, C77.2, D31.C, D32.C, J73.GND, J75.1, J76.11, J79.1, J80.3, J80.5, J80.9, J81.1, J81.2, J81.3, J81.4, J81.5, J81.6, J81.7, J82.1, J83.1, J83.2, J83.3, J83.4, J83.5, J83.6, J83.7, J83.8, J83.9, J83.10, J83.11, J83.12, J84.1, J84.2, R66.1, S19.1, S20.1, S21.1, U19.1, U19.2, U19.15, U19.33, U19.55, U20.2, U21.2
GND7: C78.2, C79.2, C80.1, C81.1, C82.2, C83.2, C84.2, C85.2, C86.2, C87.2, C88.2, D36.C, D37.C, J85.GND, J87.1, J88.11, J91.1, J92.3, J92.5, J92.9, J93.1, J93.2, J93.3, J93.4, J93.5, J93.6, J93.7, J94.1, J95.1, J95.2, J95.3, J95.4, J95.5, J95.6, J95.7, J95.8, J95.9, J95.10, J95.11, J95.12, J96.1, J96.2, R76.1, S22.1, S23.1, S24.1, U22.1, U22.2, U22.15, U22.33, U22.55, U23.2, U24.2
GND8: C89.2, C90.2, C91.1, C92.1, C93.2, C94.2, C95.2, C96.2, C97.2, C98.2, C99.2, D41.C, D42.C, J97.GND, J99.1, J100.11, J103.1, J104.3, J104.5, J104.9, J105.1, J105.2, J105.3, J105.4, J105.5, J105.6, J105.7, J106.1, J107.1, J107.2, J107.3, J107.4, J107.5, J107.6, J107.7, J107.8, J107.9, J107.10, J107.11, J107.12, J108.1, J108.2, R86.1, S25.1, S26.1, S27.1, U25.1, U25.2, U25.15, U25.33, U25.55, U26.2, U27.2
GND9: C100.2, C101.2, C102.1, C103.1, C104.2, C105.2, C106.2, C107.2, C108.2, C109.2, C110.2, D46.C, D47.C, J109.GND, J111.1, J112.11, J115.1, J116.3, J116.5, J116.9, J117.1, J117.2, J117.3, J117.4, J117.5, J117.6, J117.7, J118.1, J119.1, J119.2, J119.3, J119.4, J119.5, J119.6, J119.7, J119.8, J119.9, J119.10, J119.11, J119.12, J120.1, J120.2, R96.1, S28.1, S29.1, S30.1, U28.1, U28.2, U28.15, U28.33, U28.55, U29.2, U30.2
GND10: C111.2, C112.2, C113.1, C114.1, C115.2, C116.2, C117.2, C118.2, C119.2, C120.2, C121.2, D51.C, D52.C, J121.GND, J123.1, J124.11, J127.1, J128.3, J128.5, J128.9, J129.1, J129.2, J129.3, J129.4, J129.5, J129.6, J129.7, J130.1, J131.1, J131.2, J131.3, J131.4, J131.5, J131.6, J131.7, J131.8, J131.9, J131.10, J131.11, J131.12, J132.1, J132.2, R106.1, S31.1, S32.1, S33.1, U31.1, U31.2, U31.15, U31.33, U31.55, U32.2, U33.2
GND11: C122.2, C123.2, C124.1, C125.1, C126.2, C127.2, C128.2, C129.2, C130.2, C131.2, C132.2, D56.C, D57.C, J133.GND, J135.1, J136.11, J139.1, J140.3, J140.5, J140.9, J141.1, J141.2, J141.3, J141.4, J141.5, J141.6, J141.7, J142.1, J143.1, J143.2, J143.3, J143.4, J143.5, J143.6, J143.7, J143.8, J143.9, J143.10, J143.11, J143.12, J144.1, J144.2, R116.1, S34.1, S35.1, S36.1, U34.1, U34.2, U34.15, U34.33, U34.55, U35.2, U36.2
unnamed: R5.2, U2.5
unnamed: D5.A, R13.1
unnamed: D2.C, R6.2
unnamed: R6.1, U2.1
unnamed: D7.A, R14.1
unnamed: R16.2, U5.5
unnamed: D1.A, R3.1
unnamed: D8.C, R17.2
unnamed: R17.1, U5.1
unnamed: D6.A, R10.1
unnamed: D11.A, R23.1
unnamed: D12.A, R24.1
unnamed: R26.2, U8.5
unnamed: D13.C, R27.2
unnamed: R27.1, U8.1
unnamed: D16.A, R33.1
unnamed: D17.A, R34.1
unnamed: R36.2, U11.5
unnamed: D18.C, R37.2
unnamed: R37.1, U11.1
unnamed: D21.A, R43.1
unnamed: D22.A, R44.1
unnamed: R46.2, U14.5
unnamed: D23.C, R47.2
unnamed: R47.1, U14.1
unnamed: D26.A, R53.1
unnamed: D27.A, R54.1
unnamed: R56.2, U17.5
unnamed: D28.C, R57.2
unnamed: R57.1, U17.1
unnamed: D31.A, R63.1
unnamed: D32.A, R64.1
unnamed: R66.2, U20.5
unnamed: D33.C, R67.2
unnamed: R67.1, U20.1
unnamed: D36.A, R73.1
unnamed: D37.A, R74.1
unnamed: R76.2, U23.5
unnamed: D38.C, R77.2
unnamed: R77.1, U23.1
unnamed: D41.A, R83.1
unnamed: D42.A, R84.1
unnamed: R86.2, U26.5
unnamed: D43.C, R87.2
unnamed: R87.1, U26.1
unnamed: D46.A, R93.1
unnamed: D47.A, R94.1
unnamed: R96.2, U29.5
unnamed: D48.C, R97.2
unnamed: R97.1, U29.1
unnamed: D51.A, R103.1
unnamed: D52.A, R104.1
unnamed: R106.2, U32.5
unnamed: D53.C, R107.2
unnamed: R107.1, U32.1
unnamed: D56.A, R113.1
unnamed: D57.A, R114.1
unnamed: R116.2, U35.5
unnamed: D58.C, R117.2
unnamed: R117.1, U35.1
P0.01: R18.1, S6.2, U4.37
P0.02: J17.1, U4.39
P0.02/AIN0: J2.1, U1.11
P0.02/AIN1: J16.1, U4.11
P0.02/AIN2: J28.1, U7.11
P0.02/AIN3: J40.1, U10.11
P0.02/AIN4: J52.1, U13.11
P0.02/AIN5: J64.1, U16.11
P0.02/AIN6: J76.1, U19.11
P0.02/AIN7: J88.1, U22.11
P0.02/AIN8: J100.1, U25.11
P0.02/AIN9: J112.1, U28.11
P0.02/AIN10: J124.1, U31.11
P0.02/AIN11: J136.1, U34.11
P0.03: J17.2, U4.41
P0.03/AIN1: J2.2, U1.9
P0.03/AIN2: J16.2, U4.9
P0.03/AIN3: J28.2, U7.9
P0.03/AIN4: J40.2, U10.9
P0.03/AIN5: J52.2, U13.9
P0.03/AIN6: J64.2, U16.9
P0.03/AIN7: J76.2, U19.9
P0.03/AIN8: J88.2, U22.9
P0.03/AIN9: J100.2, U25.9
P0.03/AIN10: J112.2, U28.9
P0.03/AIN11: J124.2, U31.9
P0.03/AIN12: J136.2, U34.9
P0.04: J18.7, U4.42
P0.04/AIN1: J16.8, U4.20
P0.04/AIN2: J2.8, U1.20
P0.04/AIN3: J28.8, U7.20
P0.04/AIN4: J40.8, U10.20
P0.04/AIN5: J52.8, U13.20
P0.04/AIN6: J64.8, U16.20
P0.04/AIN7: J76.8, U19.20
P0.04/AIN8: J88.8, U22.20
P0.04/AIN9: J100.8, U25.20
P0.04/AIN10: J112.8, U28.20
P0.04/AIN11: J124.8, U31.20
P0.04/AIN12: J136.8, U34.20
P0.05: J18.6, U4.44
P0.05/AIN1: J16.7, U4.21
P0.05/AIN2: J28.7, U7.21
P0.05/AIN3: J2.7, U1.21
P0.05/AIN4: J40.7, U10.21
P0.05/AIN5: J52.7, U13.21
P0.05/AIN6: J64.7, U16.21
P0.05/AIN7: J76.7, U19.21
P0.05/AIN8: J88.7, U22.21
P0.05/AIN9: J100.7, U25.21
P0.05/AIN10: J112.7, U28.21
P0.05/AIN11: J124.7, U31.21
P0.05/AIN12: J136.7, U34.21
P0.07: R3.2, U1.23
P0.08: J3.3, R8.1, U1.24
P0.09: J18.5, U4.43
P0.09/NFC1: C11.1, J7.2, U1.52
P0.09/NFC2: C22.1, J18.2, U4.52
P0.09/NFC3: C33.1, J30.2, U7.52
P0.09/NFC4: C44.1, J42.2, U10.52
P0.09/NFC5: C55.1, J54.2, U13.52
P0.09/NFC6: C66.1, J66.2, U16.52
P0.09/NFC7: C77.1, J78.2, U19.52
P0.09/NFC8: C88.1, J90.2, U22.52
P0.09/NFC9: C99.1, J102.2, U25.52
P0.09/NFC10: C110.1, J114.2, U28.52
P0.09/NFC11: C121.1, J126.2, U31.52
P0.09/NFC12: C132.1, J138.2, U34.52
P0.10: J18.4, U4.46
P0.10/NFC1: C21.1, J18.1, U4.54
P0.10/NFC2: C10.1, J7.1, U1.54
P0.10/NFC3: C32.1, J30.1, U7.54
P0.10/NFC4: C43.1, J42.1, U10.54
P0.10/NFC5: C54.1, J54.1, U13.54
P0.10/NFC6: C65.1, J66.1, U16.54
P0.10/NFC7: C76.1, J78.1, U19.54
P0.10/NFC8: C87.1, J90.1, U22.54
P0.10/NFC9: C98.1, J102.1, U25.54
P0.10/NFC10: C109.1, J114.1, U28.54
P0.10/NFC11: C120.1, J126.1, U31.54
P0.10/NFC12: C131.1, J138.1, U34.54
P0.11: J3.4, R9.1, U1.27
P0.12: J18.3, U4.45
P0.13: R7.1, S3.2, U1.37
P0.15: J5.1, U1.39
P0.16: J15.3, R19.1, U4.24
P0.17: J5.2, U1.41
P0.18: J15.4, R20.1, U4.27
P0.19: J7.7, U1.42
P0.20: J7.6, U1.44
P0.21: J7.5, U1.43
P0.22: J7.4, U1.46
P0.23: J7.3, U1.45
P0.24: R14.2, U4.23
P0.25: R28.1, S9.2, U7.37
P0.26: J29.1, U7.39
P0.27: J29.2, U7.41
P0.28: J30.7, U7.42
P0.28/AIN1: J16.6, U4.13
P0.28/AIN2: J28.6, U7.13
P0.28/AIN3: J40.6, U10.13
P0.28/AIN4: J2.6, U1.13
P0.28/AIN5: J52.6, U13.13
P0.28/AIN6: J64.6, U16.13
P0.28/AIN7: J76.6, U19.13
P0.28/AIN8: J88.6, U22.13
P0.28/AIN9: J100.6, U25.13
P0.28/AIN10: J112.6, U28.13
P0.28/AIN11: J124.6, U31.13
P0.28/AIN12: J136.6, U34.13
P0.29: J30.6, U7.44
P0.29/AIN1: J16.5, U4.10
P0.29/AIN2: J28.5, U7.10
P0.29/AIN3: J40.5, U10.10
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

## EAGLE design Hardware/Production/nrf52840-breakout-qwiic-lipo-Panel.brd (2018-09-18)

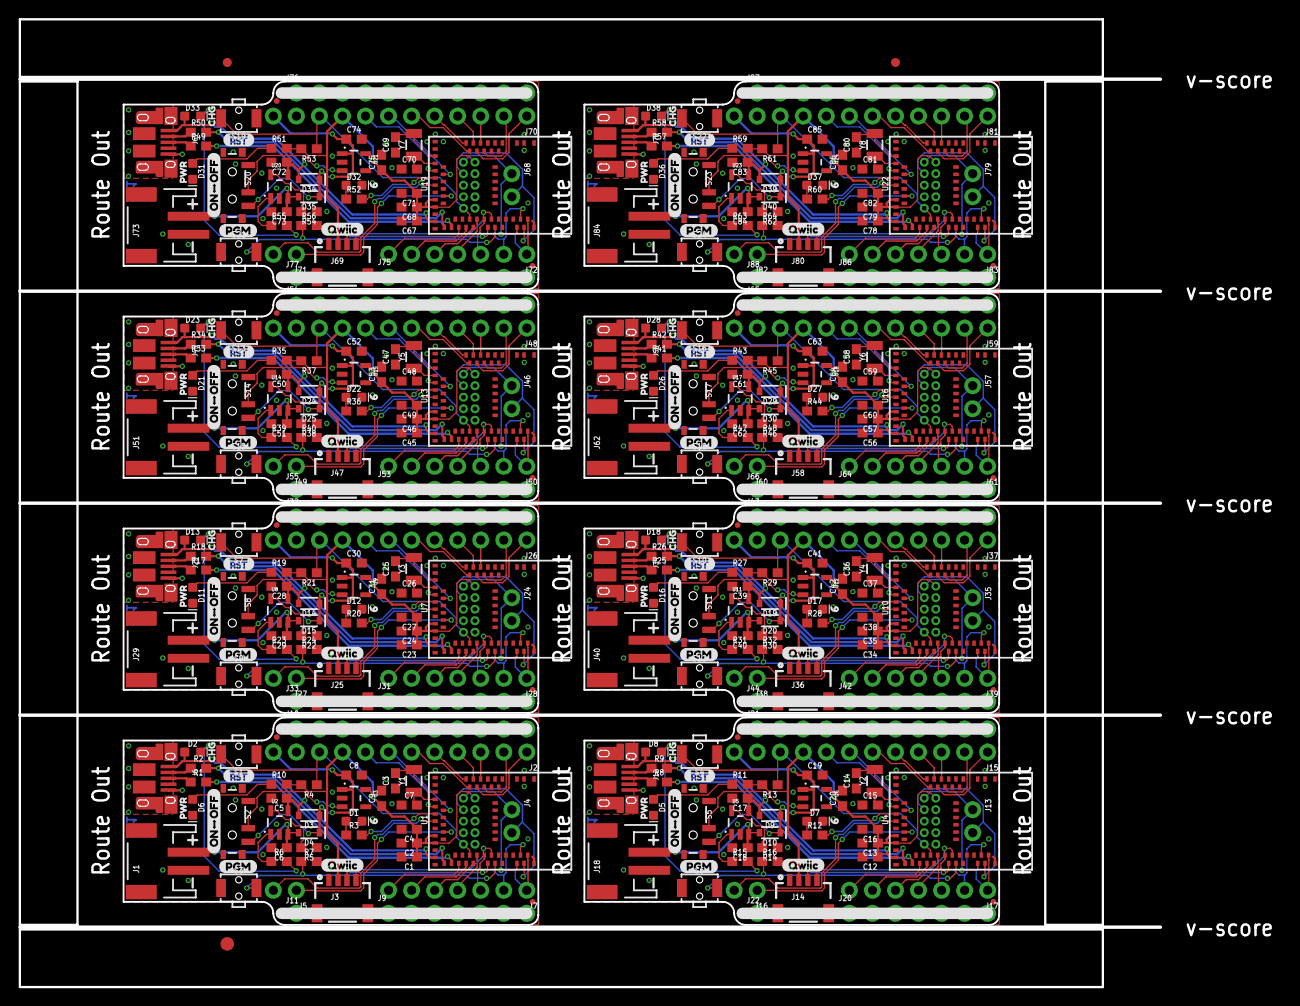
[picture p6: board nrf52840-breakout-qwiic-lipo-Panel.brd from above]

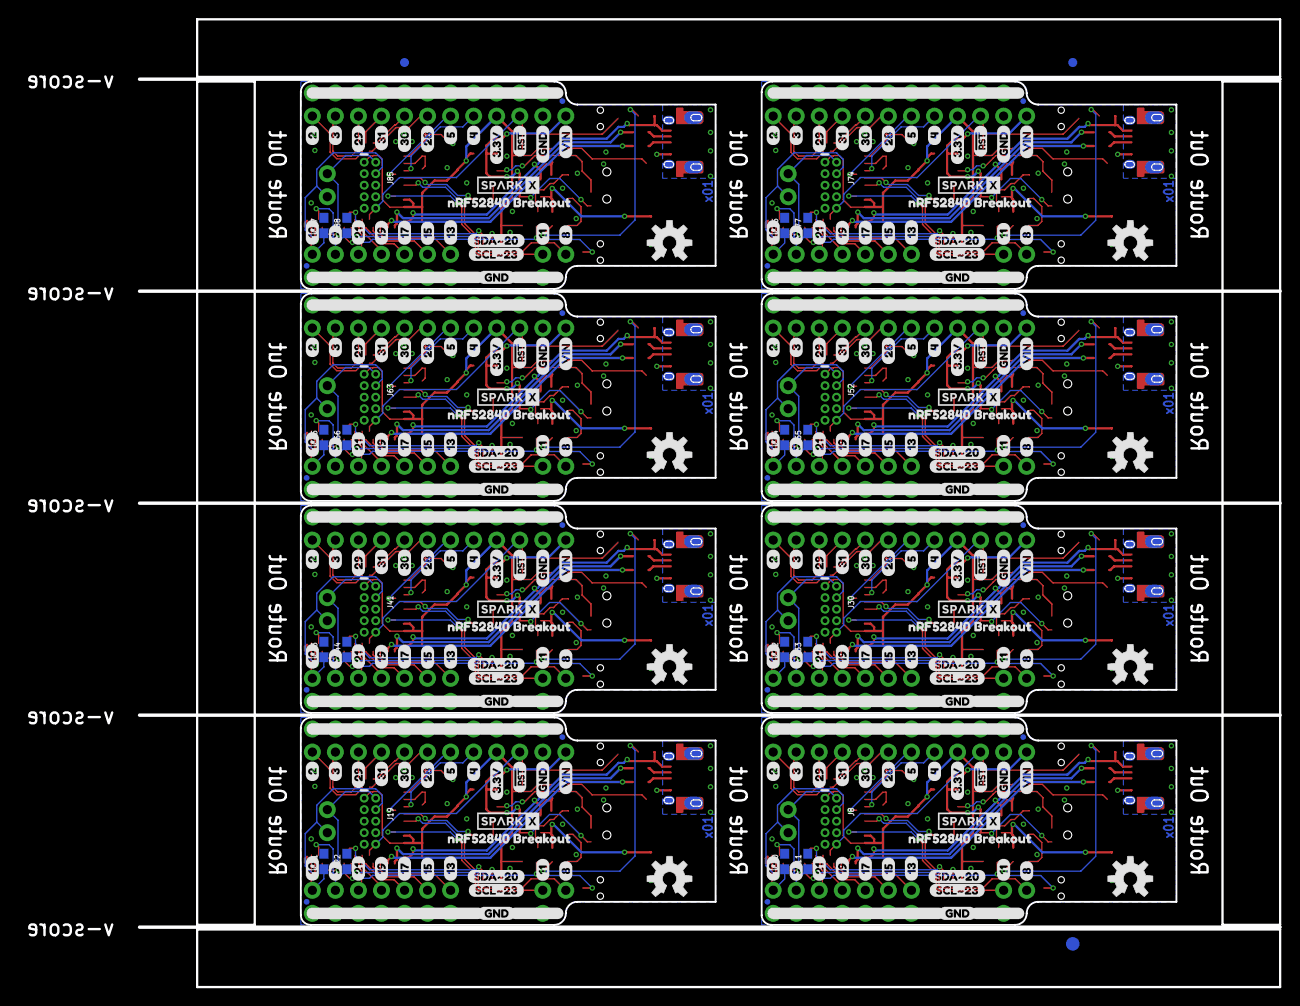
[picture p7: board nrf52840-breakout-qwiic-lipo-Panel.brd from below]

Board: 2 copper layers, 125.7 x 106.7 mm, 646 parts (259 on the bottom side), 336 nets.

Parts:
C1, C4, C12, C16, C23, C27, C34, C38, C45, C49, C56, C60, C67, C71, C78, C82: 10uF; 0603
C2, C13, C24, C35, C46, C57, C68, C79: 0.1uF; 0603
C3, C7, C14, C15, C25, C26, C36, C37, C47, C48, C58, C59, C69, C70, C80, C81: 15pF; 0603
C5, C6, C17, C18, C28, C29, C39, C40, C50, C51, C61, C62, C72, C73, C83, C84: 4.7uF; 0603
C8, C9, C19, C20, C30, C31, C41, C42, C52, C53, C63, C64, C74, C75, C85, C86: 1.0uF; 0603
C10, C11, C21, C22, C32, C33, C43, C44, C54, C55, C65, C66, C76, C77, C87, C88: DNP; 0603
D1, D7, D12, D17, D22, D27, D32, D37: GREEN; LED-0603
D2, D8, D13, D18, D23, D28, D33, D38: Yellow; LED-0603
D3, D4, D9, D10, D14, D15, D19, D20, D24, D25, D29, D30, D34, D35, D39, D40: 1A/23V/620mV; SOD-323
D5, D6, D11, D16, D21, D26, D31, D36: RED; LED-0603
E$1, E$2, E$3, E$4: FIDUCIAL-1X2
E$5, E$6: FIDUCIAL-1.5X3
FD1, FD2, FD3, FD4, FD5, FD6, FD7, FD8, FD9, FD10, FD11, FD12, FD13, FD14, FD15, FD16, FD17, FD18, FD19, FD20, FD21, FD22, FD23, FD24, FD25, FD26, FD27, FD28, FD29, FD30, FD31, FD32: FIDUCIALUFIDUCIAL; FIDUCIAL-MICRO
J1, J18, J29, J40, J51, J62, J73, J84: JST-2-SMD
J2, J15, J26, J37, J48, J59, J70, J81: 1X12_NO_SILK
J3, J14, J25, J36, J47, J58, J69, J80: 1X04_1MM_RA
J4, J5, J13, J16, J24, J27, J35, J38, J46, J49, J57, J60, J68, J71, J79, J82: 1X02_NO_SILK
J6, J12, J23, J34, J45, J56, J67, J78: USB-MICROB-PTH-MILL
J7, J9, J17, J20, J28, J31, J39, J42, J50, J53, J61, J64, J72, J75, J83, J86: 1X07_NO_SILK
J8, J19, J30, J41, J52, J63, J74, J85: CORTEX_DEBUG_PTH; 2X5-PTH-1.27MM
J10, J21, J32, J43, J54, J65, J76, J87: 1X11_NO_SILK
J11, J22, J33, J44, J55, J66, J77, J88: 1X01_NO_SILK
LOGO1, LOGO3, LOGO5, LOGO7, LOGO9, LOGO11, LOGO13, LOGO15: SPARKX-LOGO3; SPARKX-SMALL
LOGO2, LOGO4, LOGO6, LOGO8, LOGO10, LOGO12, LOGO14, LOGO16: OSHW-LOGOM; OSHW-LOGO-M
R1, R2, R8, R9, R17, R18, R25, R26, R33, R34, R41, R42, R49, R50, R57, R58: 27; 0603
R3, R6, R10, R11, R12, R15, R19, R20, R23, R27, R28, R31, R35, R36, R39, R43, R44, R47, R51, R52, R55, R59, R60, R63: 1k; 0603
R4, R7, R13, R16, R21, R24, R29, R32, R37, R40, R45, R48, R53, R56, R61, R64: 10k; 0603
R5, R14, R22, R30, R38, R46, R54, R62: 2.0k; 0603
S1, S4, S7, S10, S13, S16, S19, S22: RESET; TACTILE_SWITCH_SMD_RIGHT_ANGLE
S2, S5, S8, S11, S14, S17, S20, S23: SWITCH_SPST_SMD_A
S3, S6, S9, S12, S15, S18, S21, S24: BOOTLOAD; TACTILE_SWITCH_SMD_RIGHT_ANGLE
U1, U4, U7, U10, U13, U16, U19, U22: MDBT50Q
U2, U5, U8, U11, U14, U17, U20, U23: MCP73831; SOT23-5
U3, U6, U9, U12, U15, U18, U21, U24: 3.3V; SOT23-5
U$1, U$63, U$95, U$127, U$159, U$191, U$223, U$255: 625
U$2, U$28, U$65, U$97, U$129, U$161, U$193, U$225: #RST7
U$3, U$34, U$66, U$98, U$130, U$162, U$194, U$226: PGM2
U$4, U$35, U$67, U$99, U$131, U$163, U$195, U$227: ON#OFF4
U$5, U$36, U$68, U$100, U$132, U$164, U$196, U$228: CHG26
U$6, U$37, U$69, U$101, U$133, U$165, U$197, U$229: PWR27
U$7, U$64, U$96, U$128, U$160, U$192, U$224, U$256: 1125
U$8, U$38, U$70, U$102, U$134, U$166, U$198, U$230: QWIIC0
U$9, U$40, U$72, U$104, U$136, U$168, U$200, U$232: 20
U$10, U$41, U$73, U$105, U$137, U$169, U$201, U$233: 31
U$11, U$42, U$74, U$106, U$138, U$170, U$202, U$234: 292
U$12, U$43, U$75, U$107, U$139, U$171, U$203, U$235: 313
U$13, U$44, U$76, U$108, U$140, U$172, U$204, U$236: 304
U$14, U$45, U$77, U$109, U$141, U$173, U$205, U$237: 285
U$15, U$46, U$78, U$110, U$142, U$174, U$206, U$238: 521
U$16, U$47, U$79, U$111, U$143, U$175, U$207, U$239: 421
U$17, U$48, U$80, U$112, U$144, U$176, U$208, U$240: 3#3V5
U$18, U$49, U$81, U$113, U$145, U$177, U$209, U$241: #RST6
U$19, U$50, U$82, U$114, U$146, U$178, U$210, U$242: GND7
U$20, U$51, U$83, U$115, U$147, U$179, U$211, U$243: VIN8
U$21, U$52, U$84, U$116, U$148, U$180, U$212, U$244: 1022
U$22, U$53, U$85, U$117, U$149, U$181, U$213, U$245: 916
U$23, U$54, U$86, U$118, U$150, U$182, U$214, U$246: 2111
U$24, U$55, U$87, U$119, U$151, U$183, U$215, U$247: 1912
U$25, U$56, U$88, U$120, U$152, U$184, U$216, U$248: 1713
U$26, U$57, U$89, U$121, U$153, U$185, U$217, U$249: 1522
U$27, U$58, U$90, U$122, U$154, U$186, U$218, U$250: 1314
U$29, U$59, U$91, U$123, U$155, U$187, U$219, U$251: 816
U$30, U$39, U$71, U$103, U$135, U$167, U$199, U$231: GND6
U$31, U$60, U$92, U$124, U$156, U$188, U$220, U$252: NRF52840_BREAKOUT17
U$32, U$61, U$93, U$125, U$157, U$189, U$221, U$253: SCL#2323
U$33, U$62, U$94, U$126, U$158, U$190, U$222, U$254: SDA#2024
Y1, Y2, Y3, Y4, Y5, Y6, Y7, Y8: 32.768kHz; CRYSTAL-SMD-3.2X1.5MM

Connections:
3.3V: C1.1, C2.1, C4.1, C9.1, J2.9, J3.2, J8.1, R4.2, R7.2, R10.2, U1.28, U1.30, U3.5
3.3V1: C12.1, C13.1, C16.1, C20.1, J14.2, J15.9, J19.1, R11.2, R13.2, R16.2, U4.28, U4.30, U6.5
3.3V2: C23.1, C24.1, C27.1, C31.1, J25.2, J26.9, J30.1, R19.2, R21.2, R24.2, U7.28, U7.30, U9.5
3.3V3: C34.1, C35.1, C38.1, C42.1, J36.2, J37.9, J41.1, R27.2, R29.2, R32.2, U10.28, U10.30, U12.5
3.3V4: C45.1, C46.1, C49.1, C53.1, J47.2, J48.9, J52.1, R35.2, R37.2, R40.2, U13.28, U13.30, U15.5
3.3V5: C56.1, C57.1, C60.1, C64.1, J58.2, J59.9, J63.1, R43.2, R45.2, R48.2, U16.28, U16.30, U18.5
3.3V6: C67.1, C68.1, C71.1, C75.1, J69.2, J70.9, J74.1, R51.2, R53.2, R56.2, U19.28, U19.30, U21.5
3.3V7: C78.1, C79.1, C82.1, C86.1, J80.2, J81.9, J85.1, R59.2, R61.2, R64.2, U22.28, U22.30, U24.5
!RESET: J2.10, J8.10, R4.1, S1.2, U1.40
!RESET1: J15.10, J19.10, R13.1, S4.2, U4.40
!RESET2: J26.10, J30.10, R21.1, S7.2, U7.40
!RESET3: J37.10, J41.10, R29.1, S10.2, U10.40
!RESET4: J48.10, J52.10, R37.1, S13.2, U13.40
!RESET5: J59.10, J63.10, R45.1, S16.2, U16.40
!RESET6: J70.10, J74.10, R53.1, S19.2, U19.40
!RESET7: J81.10, J85.10, R61.1, S22.2, U22.40
D+: R1.2, U1.35
D+1: R8.2, U4.35
D+2: R17.2, U7.35
D+3: R25.2, U10.35
D+4: R33.2, U13.35
D+5: R41.2, U16.35
D+6: R49.2, U19.35
D+7: R57.2, U22.35
D+_CON: J6.D+, R1.1
D+_CON1: J12.D+, R8.1
D+_CON2: J23.D+, R17.1
D+_CON3: J34.D+, R25.1
D+_CON4: J45.D+, R33.1
D+_CON5: J56.D+, R41.1
D+_CON6: J67.D+, R49.1
D+_CON7: J78.D+, R57.1
D-: R2.2, U1.34
D-1: R9.2, U4.34
D-2: R18.2, U7.34
D-3: R26.2, U10.34
D-4: R34.2, U13.34
D-5: R42.2, U16.34
D-6: R50.2, U19.34
D-7: R58.2, U22.34
D-_CON: J6.D-, R2.1
D-_CON1: J12.D-, R9.1
D-_CON2: J23.D-, R18.1
D-_CON3: J34.D-, R26.1
D-_CON4: J45.D-, R34.1
D-_CON5: J56.D-, R42.1
D-_CON6: J67.D-, R50.1
D-_CON7: J78.D-, R58.1
GND: C1.2, C2.2, C3.1, C4.2, C5.2, C6.2, C7.1, C8.2, C9.2, C10.2, C11.2, D1.C, D6.C, J1.1, J2.11, J3.1, J6.GND, J8.3, J8.5, J8.9, J9.1, J9.2, J9.3, J9.4, J9.5, J9.6, J9.7, J10.1, J10.2, J10.3, J10.4, J10.5, J10.6, J10.7, J10.8, J10.9, J10.10, J10.11, J11.1, R5.1, S1.1, S2.3, S3.1, U1.1, U1.2, U1.15, U1.33, U1.55, U2.2, U3.2
GND1: C12.2, C13.2, C14.1, C15.1, C16.2, C17.2, C18.2, C19.2, C20.2, C21.2, C22.2, D5.C, D7.C, J12.GND, J14.1, J15.11, J18.1, J19.3, J19.5, J19.9, J20.1, J20.2, J20.3, J20.4, J20.5, J20.6, J20.7, J21.1, J21.2, J21.3, J21.4, J21.5, J21.6, J21.7, J21.8, J21.9, J21.10, J21.11, J22.1, R14.1, S4.1, S5.3, S6.1, U4.1, U4.2, U4.15, U4.33, U4.55, U5.2, U6.2
GND2: C23.2, C24.2, C25.1, C26.1, C27.2, C28.2, C29.2, C30.2, C31.2, C32.2, C33.2, D11.C, D12.C, J23.GND, J25.1, J26.11, J29.1, J30.3, J30.5, J30.9, J31.1, J31.2, J31.3, J31.4, J31.5, J31.6, J31.7, J32.1, J32.2, J32.3, J32.4, J32.5, J32.6, J32.7, J32.8, J32.9, J32.10, J32.11, J33.1, R22.1, S7.1, S8.3, S9.1, U7.1, U7.2, U7.15, U7.33, U7.55, U8.2, U9.2
GND3: C34.2, C35.2, C36.1, C37.1, C38.2, C39.2, C40.2, C41.2, C42.2, C43.2, C44.2, D16.C, D17.C, J34.GND, J36.1, J37.11, J40.1, J41.3, J41.5, J41.9, J42.1, J42.2, J42.3, J42.4, J42.5, J42.6, J42.7, J43.1, J43.2, J43.3, J43.4, J43.5, J43.6, J43.7, J43.8, J43.9, J43.10, J43.11, J44.1, R30.1, S10.1, S11.3, S12.1, U10.1, U10.2, U10.15, U10.33, U10.55, U11.2, U12.2
GND4: C45.2, C46.2, C47.1, C48.1, C49.2, C50.2, C51.2, C52.2, C53.2, C54.2, C55.2, D21.C, D22.C, J45.GND, J47.1, J48.11, J51.1, J52.3, J52.5, J52.9, J53.1, J53.2, J53.3, J53.4, J53.5, J53.6, J53.7, J54.1, J54.2, J54.3, J54.4, J54.5, J54.6, J54.7, J54.8, J54.9, J54.10, J54.11, J55.1, R38.1, S13.1, S14.3, S15.1, U13.1, U13.2, U13.15, U13.33, U13.55, U14.2, U15.2
GND5: C56.2, C57.2, C58.1, C59.1, C60.2, C61.2, C62.2, C63.2, C64.2, C65.2, C66.2, D26.C, D27.C, J56.GND, J58.1, J59.11, J62.1, J63.3, J63.5, J63.9, J64.1, J64.2, J64.3, J64.4, J64.5, J64.6, J64.7, J65.1, J65.2, J65.3, J65.4, J65.5, J65.6, J65.7, J65.8, J65.9, J65.10, J65.11, J66.1, R46.1, S16.1, S17.3, S18.1, U16.1, U16.2, U16.15, U16.33, U16.55, U17.2, U18.2
GND6: C67.2, C68.2, C69.1, C70.1, C71.2, C72.2, C73.2, C74.2, C75.2, C76.2, C77.2, D31.C, D32.C, J67.GND, J69.1, J70.11, J73.1, J74.3, J74.5, J74.9, J75.1, J75.2, J75.3, J75.4, J75.5, J75.6, J75.7, J76.1, J76.2, J76.3, J76.4, J76.5, J76.6, J76.7, J76.8, J76.9, J76.10, J76.11, J77.1, R54.1, S19.1, S20.3, S21.1, U19.1, U19.2, U19.15, U19.33, U19.55, U20.2, U21.2
GND7: C78.2, C79.2, C80.1, C81.1, C82.2, C83.2, C84.2, C85.2, C86.2, C87.2, C88.2, D36.C, D37.C, J78.GND, J80.1, J81.11, J84.1, J85.3, J85.5, J85.9, J86.1, J86.2, J86.3, J86.4, J86.5, J86.6, J86.7, J87.1, J87.2, J87.3, J87.4, J87.5, J87.6, J87.7, J87.8, J87.9, J87.10, J87.11, J88.1, R62.1, S22.1, S23.3, S24.1, U22.1, U22.2, U22.15, U22.33, U22.55, U23.2, U24.2
unnamed: R5.2, U2.5
unnamed: S2.2, U3.3
unnamed: D2.C, R6.2
unnamed: R6.1, U2.1
unnamed: D5.A, R11.1
unnamed: D7.A, R12.1
unnamed: D1.A, R3.1
unnamed: R14.2, U5.5
unnamed: D8.C, R15.2
unnamed: D6.A, R10.1
unnamed: R15.1, U5.1
unnamed: S5.2, U6.3
unnamed: D11.A, R19.1
unnamed: D12.A, R20.1
unnamed: R22.2, U8.5
unnamed: D13.C, R23.2
unnamed: R23.1, U8.1
unnamed: S8.2, U9.3
unnamed: D16.A, R27.1
unnamed: D17.A, R28.1
unnamed: R30.2, U11.5
unnamed: D18.C, R31.2
unnamed: R31.1, U11.1
unnamed: S11.2, U12.3
unnamed: D21.A, R35.1
unnamed: D22.A, R36.1
unnamed: R38.2, U14.5
unnamed: D23.C, R39.2
unnamed: R39.1, U14.1
unnamed: S14.2, U15.3
unnamed: D26.A, R43.1
unnamed: D27.A, R44.1
unnamed: R46.2, U17.5
unnamed: D28.C, R47.2
unnamed: R47.1, U17.1
unnamed: S17.2, U18.3
unnamed: D31.A, R51.1
unnamed: D32.A, R52.1
unnamed: R54.2, U20.5
unnamed: D33.C, R55.2
unnamed: R55.1, U20.1
unnamed: S20.2, U21.3
unnamed: D36.A, R59.1
unnamed: D37.A, R60.1
unnamed: R62.2, U23.5
unnamed: D38.C, R63.2
unnamed: R63.1, U23.1
unnamed: S23.2, U24.3
P0.01: J17.7, U4.37
P0.02: J17.6, U4.39
P0.02/AIN0: J2.1, U1.11
P0.02/AIN1: J15.1, U4.11
P0.02/AIN2: J26.1, U7.11
P0.02/AIN3: J37.1, U10.11
P0.02/AIN4: J48.1, U13.11
P0.02/AIN5: J59.1, U16.11
P0.02/AIN6: J70.1, U19.11
P0.02/AIN7: J81.1, U22.11
P0.03: J17.5, U4.41
P0.03/AIN1: J2.2, U1.9
P0.03/AIN2: J15.2, U4.9
P0.03/AIN3: J26.2, U7.9
P0.03/AIN4: J37.2, U10.9
P0.03/AIN5: J48.2, U13.9
P0.03/AIN6: J59.2, U16.9
P0.03/AIN7: J70.2, U19.9
P0.03/AIN8: J81.2, U22.9
P0.04: J17.4, U4.42
P0.04/AIN1: J15.8, U4.20
P0.04/AIN2: J2.8, U1.20
P0.04/AIN3: J26.8, U7.20
P0.04/AIN4: J37.8, U10.20
P0.04/AIN5: J48.8, U13.20
P0.04/AIN6: J59.8, U16.20
P0.04/AIN7: J70.8, U19.20
P0.04/AIN8: J81.8, U22.20
P0.05: J14.3, U4.44
P0.05/AIN1: J15.7, U4.21
P0.05/AIN2: J26.7, U7.21
P0.05/AIN3: J2.7, U1.21
P0.05/AIN4: J37.7, U10.21
P0.05/AIN5: J48.7, U13.21
P0.05/AIN6: J59.7, U16.21
P0.05/AIN7: J70.7, U19.21
P0.05/AIN8: J81.7, U22.21
P0.06: R3.2, U1.22
P0.07: J17.3, U4.43
P0.08: J5.2, U1.24
P0.09: R16.1, S6.2, U4.46
P0.09/NFC1: C11.1, J7.2, U1.52
P0.09/NFC2: C22.1, J17.2, U4.52
P0.09/NFC3: C33.1, J28.2, U7.52
P0.09/NFC4: C44.1, J39.2, U10.52
P0.09/NFC5: C55.1, J50.2, U13.52
P0.09/NFC6: C66.1, J61.2, U16.52
P0.09/NFC7: C77.1, J72.2, U19.52
P0.09/NFC8: C88.1, J83.2, U22.52
P0.10: J14.4, U4.45
P0.10/NFC1: C21.1, J17.1, U4.54
P0.10/NFC2: C10.1, J7.1, U1.54
P0.10/NFC3: C32.1, J28.1, U7.54
P0.10/NFC4: C43.1, J39.1, U10.54
P0.10/NFC5: C54.1, J50.1, U13.54
P0.10/NFC6: C65.1, J61.1, U16.54
P0.10/NFC7: C76.1, J72.1, U19.54
P0.10/NFC8: C87.1, J83.1, U22.54
P0.11: J5.1, U1.27
P0.12: R12.2, U4.22
P0.13: J7.7, U1.37
P0.14: J16.2, U4.24
P0.15: J7.6, U1.39
P0.16: J16.1, U4.27
P0.17: J7.5, U1.41
P0.18: J28.7, U7.37
P0.19: J7.4, U1.42
P0.20: J3.3, U1.44
P0.21: J7.3, U1.43
P0.22: R7.1, S3.2, U1.46
P0.23: J3.4, U1.45
P0.24: J28.6, U7.39
P0.25: J28.5, U7.41
P0.26: J28.4, U7.42
P0.27: J25.3, U7.44
P0.28: J28.3, U7.43
P0.28/AIN1: J15.6, U4.13
P0.28/AIN2: J26.6, U7.13
P0.28/AIN3: J37.6, U10.13
P0.28/AIN4: J2.6, U1.13
P0.28/AIN5: J48.6, U13.13
P0.28/AIN6: J59.6, U16.13
P0.28/AIN7: J70.6, U19.13
P0.28/AIN8: J81.6, U22.13
P0.29: R24.1, S9.2, U7.46
P0.29/AIN1: J15.3, U4.10
P0.29/AIN2: J26.3, U7.10
P0.29/AIN3: J37.3, U10.10
P0.29/AIN4: J48.3, U13.10
P0.29/AIN5: J2.3, U1.10
P0.29/AIN6: J59.3, U16.10
P0.29/AIN7: J70.3, U19.10
P0.29/AIN8: J81.3, U22.10
P0.30: J25.4, U7.45
P0.30/AIN1: J15.5, U4.14
P0.30/AIN2: J26.5, U7.14
P0.30/AIN3: J37.5, U10.14
P0.30/AIN4: J48.5, U13.14
P0.30/AIN5: J59.5, U16.14
P0.30/AIN6: J2.5, U1.14
P0.30/AIN7: J70.5, U19.14
P0.30/AIN8: J81.5, U22.14
P0.31: R20.2, U7.22
P0.31/AIN1: J15.4, U4.12
P0.31/AIN2: J26.4, U7.12
P0.31/AIN3: J37.4, U10.12
P0.31/AIN4: J48.4, U13.12
P0.31/AIN5: J59.4, U16.12
P0.31/AIN6: J70.4, U19.12
P0.31/AIN7: J2.4, U1.12
P0.31/AIN8: J81.4, U22.12
P0.32: J27.2, U7.24
P0.33: J27.1, U7.27
P0.34: J39.7, U10.37
P0.35: J39.6, U10.39
P0.36: J39.5, U10.41
P0.37: J39.4, U10.42
P0.38: J36.3, U10.44
P0.39: J39.3, U10.43
P0.40: R32.1, S12.2, U10.46
P0.41: J36.4, U10.45
P0.42: R28.2, U10.22
P0.43: J38.2, U10.24
P0.44: J38.1, U10.27
P0.45: J50.7, U13.37
P0.46: J50.6, U13.39
P0.47: J50.5, U13.41
P0.48: J50.4, U13.42
P0.49: J47.3, U13.44
P0.50: J50.3, U13.43
P0.51: R40.1, S15.2, U13.46
P0.52: J47.4, U13.45
P0.53: R36.2, U13.22
P0.54: J49.2, U13.24
P0.55: J49.1, U13.27
P0.56: J61.7, U16.37
P0.57: J61.6, U16.39
P0.58: J61.5, U16.41
P0.59: J61.4, U16.42
P0.60: J58.3, U16.44
P0.61: J61.3, U16.43
P0.62: R48.1, S18.2, U16.46
P0.63: J58.4, U16.45
P0.64: R44.2, U16.22
P0.65: J60.2, U16.24
P0.66: J60.1, U16.27
P0.67: J72.7, U19.37
P0.68: J72.6, U19.39
P0.69: J72.5, U19.41
P0.70: J72.4, U19.42
P0.71: J69.3, U19.44
P0.72: J72.3, U19.43
P0.73: R56.1, S21.2, U19.46
P0.74: J69.4, U19.45
P0.75: R52.2, U19.22
P0.76: J71.2, U19.24
P0.77: J71.1, U19.27
P0.78: J83.7, U22.37
P0.79: J83.6, U22.39
P0.80: J83.5, U22.41
P0.81: J83.4, U22.42
P0.82: J80.3, U22.44
P0.83: J83.3, U22.43
P0.84: R64.1, S24.2, U22.46
P0.85: J80.4, U22.45
P0.86: R60.2, U22.22
P0.87: J82.2, U22.24
P0.88: J82.1, U22.27
SHIELD: J6.SHIELD, J6.SHIELD2, J6.SHIELD3, J6.SHIELD4, J6.SHIELD5, J6.SHIELD6, J6.SHIELD7, J6.SHIELD8, J6.SHIELD9, J6.SHIELD10
SHIELD1: J12.SHIELD, J12.SHIELD2, J12.SHIELD3, J12.SHIELD4, J12.SHIELD5, J12.SHIELD6, J12.SHIELD7, J12.SHIELD8, J12.SHIELD9, J12.SHIELD10
SHIELD2: J23.SHIELD, J23.SHIELD2, J23.SHIELD3, J23.SHIELD4, J23.SHIELD5, J23.SHIELD6, J23.SHIELD7, J23.SHIELD8, J23.SHIELD9, J23.SHIELD10
SHIELD3: J34.SHIELD, J34.SHIELD2, J34.SHIELD3, J34.SHIELD4, J34.SHIELD5, J34.SHIELD6, J34.SHIELD7, J34.SHIELD8, J34.SHIELD9, J34.SHIELD10
SHIELD4: J45.SHIELD, J45.SHIELD2, J45.SHIELD3, J45.SHIELD4, J45.SHIELD5, J45.SHIELD6, J45.SHIELD7, J45.SHIELD8, J45.SHIELD9, J45.SHIELD10
SHIELD5: J56.SHIELD, J56.SHIELD2, J56.SHIELD3, J56.SHIELD4, J56.SHIELD5, J56.SHIELD6, J56.SHIELD7, J56.SHIELD8, J56.SHIELD9, J56.SHIELD10
SHIELD6: J67.SHIELD, J67.SHIELD2, J67.SHIELD3, J67.SHIELD4, J67.SHIELD5, J67.SHIELD6, J67.SHIELD7, J67.SHIELD8, J67.SHIELD9, J67.SHIELD10
SHIELD7: J78.SHIELD, J78.SHIELD2, J78.SHIELD3, J78.SHIELD4, J78.SHIELD5, J78.SHIELD6, J78.SHIELD7, J78.SHIELD8, J78.SHIELD9, J78.SHIELD10
SWDCLK: J4.2, J8.4, U1.53
SWDCLK1: J13.2, J19.4, U4.53
SWDCLK2: J24.2, J30.4, U7.53
SWDCLK3: J35.2, J41.4, U10.53
SWDCLK4: J46.2, J52.4, U13.53
SWDCLK5: J57.2, J63.4, U16.53
SWDCLK6: J68.2, J74.4, U19.53
SWDCLK7: J79.2, J85.4, U22.53
SWDIO: J4.1, J8.2, U1.51
SWDIO1: J13.1, J19.2, U4.51
SWDIO2: J24.1, J30.2, U7.51
SWDIO3: J35.1, J41.2, U10.51
SWDIO4: J46.1, J52.2, U13.51
SWDIO5: J57.1, J63.2, U16.51
SWDIO6: J68.1, J74.2, U19.51
SWDIO7: J79.1, J85.2, U22.51
VIN: C8.1, D3.C, D4.C, J2.12, S2.1, U3.1
VIN1: C19.1, D9.C, D10.C, J15.12, S5.1, U6.1
VIN2: C30.1, D14.C, D15.C, J26.12, S8.1, U9.1
VIN3: C41.1, D19.C, D20.C, J37.12, S11.1, U12.1
VIN4: C52.1, D24.C, D25.C, J48.12, S14.1, U15.1
VIN5: C63.1, D29.C, D30.C, J59.12, S17.1, U18.1
VIN6: C74.1, D34.C, D35.C, J70.12, S20.1, U21.1
VIN7: C85.1, D39.C, D40.C, J81.12, S23.1, U24.1
V_BATT: C6.1, D4.A, J1.2, U2.3
V_BATT1: C18.1, D10.A, J18.2, U5.3
V_BATT2: C29.1, D15.A, J29.2, U8.3
V_BATT3: C40.1, D20.A, J40.2, U11.3
V_BATT4: C51.1, D25.A, J51.2, U14.3
V_BATT5: C62.1, D30.A, J62.2, U17.3
V_BATT6: C73.1, D35.A, J73.2, U20.3
V_BATT7: C84.1, D40.A, J84.2, U23.3
V_USB: C5.1, D2.A, D3.A, J6.VBUS, U1.32, U2.4
V_USB1: C17.1, D8.A, D9.A, J12.VBUS, U4.32, U5.4
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

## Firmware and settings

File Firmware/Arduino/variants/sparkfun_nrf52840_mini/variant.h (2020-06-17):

 /*
  Copyright (c) 2014-2015 Arduino LLC.  All right reserved.
  Copyright (c) 2016 Sandeep Mistry All right reserved.
  Copyright (c) 2018, Adafruit Industries (adafruit.com)

  This library is free software; you can redistribute it and/or
  modify it under the terms of the GNU Lesser General Public
  License as published by the Free Software Foundation; either
  version 2.1 of the License, or (at your option) any later version.
  This library is distributed in the hope that it will be useful,
  but WITHOUT ANY WARRANTY; without even the implied warranty of
  MERCHANTABILITY or FITNESS FOR A PARTICULAR PURPOSE.
  See the GNU Lesser General Public License for more details.
  You should have received a copy of the GNU Lesser General Public
  License along with this library; if not, write to the Free Software
  Foundation, Inc., 51 Franklin St, Fifth Floor, Boston, MA  02110-1301  USA
*/

#ifndef _VARIANT_SPARKFUN52840MINI_
#define _VARIANT_SPARKFUN52840MINI_

/** Master clock frequency */
#define VARIANT_MCK       (64000000ul)

#define USE_LFXO      // Board uses 32khz crystal for LF
// define USE_LFRC    // Board uses RC for LF

/*----------------------------------------------------------------------------
 *        Headers
 *----------------------------------------------------------------------------*/

#include "WVariant.h"

#ifdef __cplusplus
extern "C"
{
#endif // __cplusplus

// Number of pins defined in PinDescription array
#define PINS_COUNT           (64)
#define NUM_DIGITAL_PINS     (64)
#define NUM_ANALOG_INPUTS    (8)
#define NUM_ANALOG_OUTPUTS   (0)

// LEDs
#define PIN_LED1             (7)
#define PIN_LED2             (14)

#define LED_BUILTIN          PIN_LED1
#define LED_CONN             PIN_LED2

#define LED_BLUE             PIN_LED1
#define LED_RED              PIN_LED2

#define LED_STATE_ON         1         // State when LED is litted

// Buttons
/*
#define PIN_BUTTON1             (2)
#define PIN_BUTTON2             (3)
#define PIN_BUTTON3             (4)
#define PIN_BUTTON4             (5)
*/

/*
 * Analog pins
 */
#define PIN_A0               (2)
#define PIN_A1               (3)
#define PIN_A2               (4)
#define PIN_A3               (5)
#define PIN_A4               (28)
#define PIN_A5               (29)
#define PIN_A6               (30)
#define PIN_A7               (31)

static const uint8_t A0  = PIN_A0 ;
static const uint8_t A1  = PIN_A1 ;
static const uint8_t A2  = PIN_A2 ;
static const uint8_t A3  = PIN_A3 ;
static const uint8_t A4  = PIN_A4 ;
static const uint8_t A5  = PIN_A5 ;
static const uint8_t A6  = PIN_A6 ;
static const uint8_t A7  = PIN_A7 ;
#define ADC_RESOLUTION    14

// Other pins
#define PIN_AREF           (2)
#define PIN_DFU            (13)
#define PIN_NFC1           (9)
#define PIN_NFC2           (10)

static const uint8_t AREF = PIN_AREF;

/*
 * Serial interfaces
 */
// Serial
//Previous Hardware UART definition for nRF52 Arduino Core, below 0.16.0
//Feel free to comment out these two lines below if there are conflicts with latest release
//06/16/20 - the "Serial" bus is the Serial USB interface. Defining pins for "Serial" does not make any sense.
// #define PIN_SERIAL_RX       (15)
// #define PIN_SERIAL_TX       (17)

//Hardware UART definition for nRF52 Arduino Core, 0.17.0 and above
#define PIN_SERIAL1_RX      (15)
#define PIN_SERIAL1_TX      (17)

//06/16/20 - Added the second serial bus
#define PIN_SERIAL2_RX      (19)
#define PIN_SERIAL2_TX      (20)

/*
 * SPI Interfaces
 */
#define SPI_INTERFACES_COUNT 1

#define PIN_SPI_MISO         (31)
#define PIN_SPI_MOSI         (3)
#define PIN_SPI_SCK          (30)

static const uint8_t SS   = 2 ;
static const uint8_t MOSI = PIN_SPI_MOSI ;
static const uint8_t MISO = PIN_SPI_MISO ;
static const uint8_t SCK  = PIN_SPI_SCK ;

/*
 * Wire Interfaces
 */
#define WIRE_INTERFACES_COUNT 1

#define PIN_WIRE_SDA         (8)
#define PIN_WIRE_SCL         (11)

/*
 * QSPI interface for external flash
 */
#define PIN_QSPI_SCK         32
#define PIN_QSPI_CS          33
#define PIN_QSPI_DATA0       34
#define PIN_QSPI_DATA1       35
#define PIN_QSPI_DATA2       36
#define PIN_QSPI_DATA3       37

// On-board QSPI Flash
// If EXTERNAL_FLASH_DEVICES is not defined, all supported devices will be used
#define EXTERNAL_FLASH_DEVICES   GD25Q16C

#ifdef __cplusplus
}
#endif

/*----------------------------------------------------------------------------
 *        Arduino objects - C++ only
 *----------------------------------------------------------------------------*/

#endif

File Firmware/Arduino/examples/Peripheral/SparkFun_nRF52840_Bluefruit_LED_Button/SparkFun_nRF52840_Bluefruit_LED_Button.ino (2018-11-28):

/* BLE Example for SparkFun Pro nRF52840 Mini 
 *  
 *  This example demonstrates how to use the Bluefruit
 *  library to both send and receive data to the
 *  nRF52840 via BLE.
 *  
 *  Using a BLE development app like Nordic's nRF Connect
 *  https://www.nordicsemi.com/eng/Products/Nordic-mobile-Apps/nRF-Connect-for-Mobile
 *  The BLE UART service can be written to to turn the
 *  on-board LED on/off, or read from to monitor the 
 *  status of the button.
 *  
 *  See the tutorial for more information:
 *  https://learn.sparkfun.com/tutorials/nrf52840-development-with-arduino-and-circuitpython#arduino-examples  
*/
#include <bluefruit.h>

BLEUart bleuart; // uart over ble

// Define hardware: LED and Button pins and states
const int LED_PIN = 7;
#define LED_OFF LOW
#define LED_ON HIGH

const int BUTTON_PIN = 13;
#define BUTTON_ACTIVE LOW
int lastButtonState = -1;

void setup() {
  // Initialize hardware:
  Serial.begin(9600); // Serial is the USB serial port
  pinMode(LED_PIN, OUTPUT); // Turn on-board blue LED off
  digitalWrite(LED_PIN, LED_OFF);
  pinMode(BUTTON_PIN, INPUT);

  // Uncomment the code below to disable sharing
  // the connection LED on pin 7.
  //Bluefruit.autoConnLed(false);

  // Initialize Bluetooth:
  Bluefruit.begin();
  // Set max power. Accepted values are: -40, -30, -20, -16, -12, -8, -4, 0, 4
  Bluefruit.setTxPower(4);
  Bluefruit.setName("SparkFun_nRF52840");
  bleuart.begin();

  // Start advertising device and bleuart services
  Bluefruit.Advertising.addFlags(BLE_GAP_ADV_FLAGS_LE_ONLY_GENERAL_DISC_MODE);
  Bluefruit.Advertising.addTxPower();
  Bluefruit.Advertising.addService(bleuart);
  Bluefruit.ScanResponse.addName();
  
  Bluefruit.Advertising.restartOnDisconnect(true);
  // Set advertising interval (in unit of 0.625ms):
  Bluefruit.Advertising.setInterval(32, 244);
  // number of seconds in fast mode:
  Bluefruit.Advertising.setFastTimeout(30);
  Bluefruit.Advertising.start(0);  
}

void loop() {
  // If data has come in via BLE:
  if (bleuart.available()) {
    uint8_t c;
    // use bleuart.read() to read a character sent over BLE
    c = (uint8_t) bleuart.read();
    // Print out the character for debug purposes:
    Serial.write(c);

    // If the character is one of our expected values,
    // do something:
    switch (c) {
      // 0 number or character, turn the LED off:
      case 0:
      case '0':
        digitalWrite(LED_PIN, LED_OFF);
        break;
      // 1 number or character, turn the LED on:
      case 1:
      case '1':
        digitalWrite(LED_PIN, LED_ON);
        break;
      default:
        break;
    }
  }

  // If our button state has changed:
  int buttonState = digitalRead(BUTTON_PIN);
  if (buttonState != lastButtonState) {
    lastButtonState = buttonState;
    // Write the new button state to the bleuart TX char
    bleuart.write(!buttonState);
  }
}

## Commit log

2018-08-30 initial commit -- hardware (x01)
    [nrf52840-breakout-qwiic-lipo.brd, nrf52840-breakout-qwiic-lipo.sch]
2018-09-18 Adding x01 panel
    [nrf52840-breakout-qwiic-lipo-Panel.GBL, nrf52840-breakout-qwiic-lipo-Panel.GBO, nrf52840-breakout-qwiic-lipo-Panel.GBP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]
2018-09-25 Revisions preparing for v10
    - Rearranged pin breakouts, qwiic connection, LED, and button
    - Flipped on/off switch towards module for easier access
    - Expanded board 50mil to facilitate soldering pins near buttons
    - Labeled pins on top side
    - Increased VBAT and VUSB power trace width
    [nrf52840-breakout-mdbt50q.brd, nrf52840-breakout-mdbt50q.sch, nrf52840-breakout-qwiic-lipo.brd]
2018-09-25 Board revisions post engineer checklist
    - Added extra ground PTH
    - Added production sku for nRF module
    - Added link to tutorial
    - Clean up schematic
    [nrf52840-breakout-mdbt50q.brd, nrf52840-breakout-mdbt50q.sch]
2018-09-25 Adding pull-up resistors to I2C lines.
    [nrf52840-breakout-mdbt50q.brd, nrf52840-breakout-mdbt50q.sch]
2018-09-27 Engineering review revisions
    - Increase USB data line clearance to 10mil
    - Move silkscreen to better-avoid stop
    - Add silk to indicate ADC pins
    - Minor trace re-routing
    [nrf52840-breakout-mdbt50q.brd, nrf52840-breakout-mdbt50q.sch]
2018-09-27 Setting grid to default.
    [nrf52840-breakout-mdbt50q.brd]
2018-10-03 panel v10 created
    [14113-nrf52840-breakout-mdbt50q-Panel.brd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]
2018-10-05 Fixing silk on 28, 29, 30 bottom side
    [nrf52840-breakout-mdbt50q.brd]
2018-10-05 Flipping board
    [nrf52840-breakout-mdbt50q.brd]
2018-10-05 Updated silk
    [14113-nrf52840-breakout-mdbt50q-Panel.brd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]
2018-11-27 Adding board pin definitions for nRF5 SDK.
2018-11-27 Fixing LED active state definition -- active-high.
2018-11-28 Adding sparkfun board definitions for nRF52 Adafruit.
2018-11-28 Adding BLE button/LED peripheral example.
2018-11-28 Adding optional connect-LED disable.
2019-07-17 Update board definition
    Owen solved compiler issue: Adafruit switch to using TinyUSB in the core. The following changes update the board definition to use TinyUSB
2019-07-17 Update for TinyUSB
    USB is initialized with TinyUSB core in the build.
    https://github.com/sparkfun/nRF52840_Breakout_MDBT50Q/blob/master/Firmware/Arduino/sparkfun_boards.txt#L38
2019-12-18 Update variant.h
    Fixing mismatched analog pin definitions to match schematic and datasheet of the nRF52840 (MDBT50Q).
    [variant.h]
2020-05-29 Update variant.h
    There are updates to the nRF52 Arduino core files that broke a few things. More information can be found here:
    https://github.com/sparkfun/nRF52840_Breakout_MDBT50Q/issues/7
    Adding additional defines for the hardware uart pins for anyone using nRF52 Arduino Core files, 0.17.0 and above.
    [variant.h]
2020-06-17 Corrected serial pin definitions
    "Serial" is USB serial, so we don't need to define any hardware pins. Left the original pins for "Serial1" and added the pin definitions for "Serial2".
    [variant.h]

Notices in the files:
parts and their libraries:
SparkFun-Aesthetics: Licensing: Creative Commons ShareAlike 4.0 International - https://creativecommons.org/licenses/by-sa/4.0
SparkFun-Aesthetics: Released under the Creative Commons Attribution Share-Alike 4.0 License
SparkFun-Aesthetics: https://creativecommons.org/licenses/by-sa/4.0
